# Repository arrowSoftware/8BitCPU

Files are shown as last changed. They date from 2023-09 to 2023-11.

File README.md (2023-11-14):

# 8BitCPU
8-Bit CPU

# Table of Contents
- [References](#references)
- [TODO](#todo)
- [Instruction set](#instruction-set)
  - [Instructions](#instructions)
  - [Microcodes](#microcodes)
  - [Instruction microcode decriptions](#instruction-microcode-decriptions)
  - [Logisim Instructions Testing](#logisim-instructions-testing)
    - [NOP & HLT](#nop-hlt)
    - [LDA NUM](#lda-num)
    - [LDA [ADDR]](#lda-addr)
    - [STA [ADDR]](#sta-addr)
    - [LDB [NUM]](#ldb-num)
    - [LDB [ADDR]](#ldb-addr)
    - [STB [ADDR]](#stb-addr)
    - [ADD NUM](#add-num)
    - [ADD [ADDR]](#add-addr)
    - [SUB NUM](#sub-num)
    - [SUB [ADDR]](#sub-addr)
    - [AND NUM](#add-num)
    - [AND [ADDR]](#and-addr)
    - [OR NUM](#or-num)
    - [OR [ADDR]](#or-addr)
    - [XOR NUM](#xor-num)
    - [XOR [ADDR]](#xor-addr)
    - [NOTA](#nota)
    - [NOT [ADDR]](#not-addr)
    - [OUTA](#outa)
    - [OUTB](#outb)
    - [OUT NUM](#out-num)
    - [OUT [ADDR]](#out-addr)
    - [JMP [ADDR]](#jmp-addr)
    - [JPZ [ADDR]](#jpz-addr)
    - [JPC [ADDR]](#jpc-addr)
    - [RST](#rst)
    - [Fibinacci test](#fibinacci-test)
    - [Multiplication test](#multiplication-test)
- [CPU Design](#cpu-design)
  - [Register](#register)
    - [D-Flip-Flop](#d-flip-flop)
    - [Available registers in this project](#available-registers-in-this-project)
  - [Half Adder](#half-adder)
  - [Full Adder](#full-adder)
  - [8-Bit Adder](#8-bit-adder)
  - [D-Latch](#d-latch)
  - [4-Bit Binary Decoder](#4-bit-binary-decoder)
  - [Multiplexer](#multiplexer)
    - [1-Bit Multiplexer](#1-bit-multiplexer)
    - [8-Bit Multiplexer](#8-bit-multiplexer)
    - [8-Bit 2x1 Multiplexer](#8-bit-2x1-multiplexer)
    - [8-Bit 4x1 Multiplexer](#8-bit-4x1-multiplexer)
  - [8-Bit Clear](#8-bit-clear)
  - [8-Bit Inverter](#8-bit-inverter)
  - [8-Bit OR](#8-bit-or)
  - [8-Bit AND](#8-bit-and)
  - [8-Bit XOR](#8-bit-xor)
  - [8-Bit ALU](#8-bit-alu)
  - [4-Bit Decoder - 7 Segment](#4-bit-decoder---7-segment)
  - [8-Bit Decoder - 7 Segment](#8-bit-decoder---7-segment)
  - [8-Bit Reverser](#8-bit-reverser)
  - [SRAM](#sram)
    - [16-Byte SRAM](#16-byte-sram)
    - [256-Byte SRAM](#256-byte-sram)
  - [Program Loader](#program-loader)
  - [8-Bit Processor](#8-bit-processor)
- [Assembler](#assembler)
  - [Building](#building)
  - [Number Formats](#number-formats)
  - [Label Formats](#label-formats)
  - [Instruction Formats](#instruction-formats)
  - [Output files](#output-files)
  - [Example Output](#example-output)
  - [Warnings & Errors](#warnings--errors)
  - [Reference assembler outputs](#reference-assembler-outputs)
- [Objdump](#objdump)
- [Emulator](#emulator)

## References
* https://schweigi.github.io/assembler-simulator/
* https://schweigi.github.io/assembler-simulator/instruction-set.html
* https://users.informatik.haw-hamburg.de/~krabat/FH-Labor/gnupro/5_GNUPro_Utilities/c_Using_LD/ldLinker_scripts.html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
* https://github.com/leonicolas/computer-8bits
* https://www.daniellowengrub.com/blog/2021/02/08/binary-counter
* https://github.com/hlorenzi/customasm
* https://cs.lmu.edu/~ray/notes/nasmtutorial/
### Backplane references
* https://github.com/daveho/easycpu
* https://hackaday.io/project/190621-zara80/log/218492-5-slot-stebus-backplane-rev-1
* https://tclarke.github.io/zara80/stebus-backplane.svg
* https://blondihacks.com/wp-content/uploads/2011/12/Backplane_Sch.jpg
* https://smallcomputercentral.files.wordpress.com/2018/09/modular-backplane-specification-v0-4-2018-09-19.pdf

## TODO

## Instruction set
The instruction set implemented in this project is CISC (Complex Instruction Set Computers) based.

### Instructions
|Instruction | OpCode | Description |
|:---|:---|:---|
|NOP |0x00 |No operation. Fetches the next operation.|
|HLT |0x01 |Stops the clock.|
|LDA NUM |0x02 |Loads register A with the given value.|
|LDA [ADDR]  |0x03 |Loads register A with the value stored in the given memory address.|
|STA [ADDR]  |0x04 |Stores the register A value in the given memory address.|
|LDB NUM |0x05 |Loads register B with the given value.|
|LDB [ADDR]  |0x06 |Loads register B with the value stored in the given memory address.|
|STB [ADDR]  |0x07 |Stores the register B value in the given memory address.|
|ADD NUM |0x08 |Adds the given value with the value stored in register A and stores the sum result in register A. The given number will be stored in register B.|
|ADD [ADDR]  |0x09 |Adds the value stored in the given memory address with the value stored in register A. Stores the sum result in register A.|
|SUB NUM |0x0A |Subtracts the given value with the value stored in register A and stores the subtraction result in register A. The given number will be stored in register B.|
|SUB [ADDR]  |0x0B |Subtracts the value stored in the given memory address with the value stored in register A. Stores the subtraction result in register A.|
|AND NUM |0x0C |TODO|
|ADD [ADDR]  |0x0D |TODO|
|OR NUM |0x0E |TODO|
|OR [ADDR] |0x0F |TODO|
|XOR NUM |0x10 |TODO|
|XOR [ADDR]  |0x11 |TODO|
|NOTA |0x12 |TODO|
|NOT [ADDR]  |0x13 |TODO|
|OUTA |0x14 |Sets the Output register with the register A value.|
|OUTB |0x15 |Sets the Output register with the register B value.|
|OUT NUM |0x16 |Sets the Output register with the given value.|
|OUT [ADDR]  |0x17 |Sets the Output register with the value stored in the given memory address.|
|JMP [ADDR]  |0x18 |Jumps to the given address.|
|JPZ [ADDR]  |0x19 |Jumps to the given address if the zero flag is 1.|
|JPC [ADDR]  |0x1A |Jumps to the given address if the carry flag is 1.|
|UNUSED |0x1B |Spare expansion.|
|UNUSED |0x1C |Spare expansion.|
|UNUSED |0x1D |Spare expansion.|
|RST |0x1E |Reset the cpu (TODO).|

### Microcodes
* FLG = FLAG REGISTER
  * FI = Enable flag register load.
    * Loads the flags register with the value currently on the data bus.
    * Available flags:
    * | Flag | Description   |
      |------|---------------|
      | CF   | Carry Flag    |
      | ZF   | Zero Flag     |
      | NF   | Negative Flag |
      | VF   | Overflow Flag |
* CL = CLOCK
  * HL = Halt clock.
    * Stops the clock.
* AR = A REGISTER
  * AI = Enable A register load.
    * Loads the A register with the value currently on the data bus.
  * AO = Enable A regsiter output.
    * Outputs the current register value to the data bus.
* ALU = ALGORITHMIC AND LOGIC UNIT
  * EO = Enable ALU output.
    * Outputs the current ALU operation result to the data bus.
  * CI = Carry in flag.
    * Carry in flag from Flag register
  * SEL = ALU operation select code
    * 3 bit number for selecting the ALU operation.
    * | code | operation      |
      |------|----------------|
      |000   | A OR B         |
      |001   | NOT A          |
      |010   | A + NOT B + Ci |
      |011   | A + B + Ci     |
      |100   | A XOR B        |
      |101   | A AND B        |
      |110   | A - 1 + Ci     |
* BR = B REGISTER
  * BI = Enable B register load.
    * Loads the A register with the value currently on the data bus.
  * BO = Enable B regsiter output.
    * Outputs the current register value to the data bus.
* MR = MEMORY REGISTER
  * MI = Enable memory register load.
    * Loads the memory register with the value currently on the data bus.
* RAM = RANDOM ACCESS MEMORY
  * RW = Enable RAM write.
    * Writes the value currently on the data bus into the selected memory banks.
  * RR = Enable RAM read.
    * Outputs the value stored in the selected memory bank to the data bus.
* IR = INSTRUCTION REGISTER
  * II = Enable instruction register load.
    * Loads the instruction register with the value currently on the data bus.
  * IR = Reset instruction register.
    * Resets the instruction decoder counter back to 0. (Fetch next instruction set)
* PC = PROGRAM COUNTER REGISTER
  * CE = Enable counter register.
    * Enables the program counter to process the count.
  * CO = Enable counter register output.
    * Ouputs the current register value to the data bus.
  * JP = Enable counter register load.
    * Loads the program counter register with the value currently on the data bus.
* OR = OUTPUT REGISTER
  * OI = Enable output register load.
    * Loads the output register with the value currently on the data bus.

### Instruction microcode decriptions

* Control Flags is a bit mapping of each microword.
* OpCode in column 2 is the assembly opcode value.
* OpCode in second to last column is the microcode opcode value.

| Instruction | OpCode |CF |ZF |VF |NF |Step  |FI |HL |AI |AO |SEL  |EO |CI |BI |BO |MI |RW |RR |II |IR |CE |CO |JP |OI |OpCode  |Control Flags  |
|:---|:---:|:-:|:-:|:-:|:-:|:----:|:-:|:-:|:-:|:-:|:---:|:-:|:-:|:-:|:-:|:-:|:-:|:-:|:-:|:-:|:-:|:-:|:-:|:-:|:---:|:---:|
|FETCH INSTR  |XXXXX | X | X | X | X |0 | 0 | 0 | 0 | 0 | XXX | 0 | 0 | 0 | 0 | 1 | 0 | 0 | 0 | 0 | 0 | 1 | 0 | 0 | XX | 00104 |
| |XXXXX | X | X | X | X |1 | 0 | 0 | 0 | 0 | XXX | 0 | 0 | 0 | 0 | 0 | 0 | 1 | 1 | 0 | 1 | 0 | 0 | 0 | XX | 00068 |
|FIN INSTR |XXXXX | X | X | X | X |X | X | X | X | 0 | XXX | 0 | 0 | 0 | 0 | 0 | 0 | 0 | 0 | 1 | 0 | 0 | 0 | 0 | XX | 00010 |
| | | | | | | | | | | | | | | | | | | | | | | | | | | |
|NOP |00000 | X | X | X | X |2 | 0 | 0 | 0 | 0 | XXX | 0 | 0 | 0 | 0 | 0 | 0 | 0 | 0 | 1 | 0 | 0 | 0 | 0 | 00 | 00010 |
|HLT |00001 | X | X | X | X |2 | 0 | 1 | 0 | 0 | XXX | 0 | 0 | 0 | 0 | 0 | 0 | 0 | 0 | 0 | 0 | 0 | 0 | 0 | 01 | 40000 |
|LDA NUM |00010 | X | X | X | X |2 | 0 | 0 | 0 | 0 | XXX | 0 | 0 | 0 | 0 | 1 | 0 | 0 | 0 | 0 | 1 | 1 | 0 | 0 | 02 | 0010C |
| |00010 | X | X | X | X |3 | 0 | 0 | 1 | 0 | XXX | 0 | 0 | 0 | 0 | 0 | 0 | 1 | 0 | 0 | 0 | 0 | 0 | 0 | 02 | 20040 |
|LDA [ADDR] |00011 | X | X | X | X |2 | 0 | 0 | 0 | 0 | XXX | 0 | 0 | 0 | 0 | 1 | 0 | 0 | 0 | 0 | 1 | 1 | 0 | 0 | 03 | 0010C |
| |00011 | X | X | X | X |3 | 0 | 0 | 0 | 0 | XXX | 0 | 0 | 0 | 0 | 1 | 0 | 1 | 0 | 0 | 0 | 0 | 0 | 0 | 03 | 00140 |
| |00011 | X | X | X | X |4 | 0 | 0 | 1 | 0 | XXX | 0 | 0 | 0 | 0 | 0 | 0 | 1 | 0 | 0 | 0 | 0 | 0 | 0 | 03 | 20040 |
|STA [ADDR] |00100 | X | X | X | X |2 | 0 | 0 | 0 | 0 | XXX | 0 | 0 | 0 | 0 | 1 | 0 | 0 | 0 | 0 | 1 | 1 | 0 | 0 | 04 | 0010C |
| | | X | X | X | X |3 | 0 | 0 | 0 | 0 | XXX | 0 | 0 | 0 | 0 | 1 | 0 | 1 | 0 | 0 | 0 | 0 | 0 | 0 | 04 | 00140 |
| | | X | X | X | X |4 | 0 | 0 | 0 | 1 | XXX | 0 | 0 | 0 | 0 | 0 | 1 | 0 | 0 | 0 | 0 | 0 | 0 | 0 | 04 | 10080 |
|LDB NUM |00101 | X | X | X | X |2 | 0 | 0 | 0 | 0 | XXX | 0 | 0 | 0 | 0 | 1 | 0 | 0 | 0 | 0 | 1 | 1 | 0 | 0 | 05 | 0010C |
| | | X | X | X | X |3 | 0 | 0 | 0 | 0 | XXX | 0 | 0 | 1 | 0 | 0 | 0 | 1 | 0 | 0 | 0 | 0 | 0 | 0 | 05 | 00440 |
|LDB [ADDR] |00110 | X | X | X | X |2 | 0 | 0 | 0 | 0 | XXX | 0 | 0 | 0 | 0 | 1 | 0 | 0 | 0 | 0 | 1 | 1 | 0 | 0 | 06 | 0010C |
| | | X | X | X | X |3 | 0 | 0 | 0 | 0 | XXX | 0 | 0 | 0 | 0 | 1 | 0 | 1 | 0 | 0 | 0 | 0 | 0 | 0 | 06 | 00140 |
| | | X | X | X | X |4 | 0 | 0 | 0 | 0 | XXX | 0 | 0 | 1 | 0 | 0 | 0 | 1 | 0 | 0 | 0 | 0 | 0 | 0 | 06 | 00440 |
|STB [ADDR] |00111 | X | X | X | X |2 | 0 | 0 | 0 | 0 | XXX | 0 | 0 | 0 | 0 | 1 | 0 | 0 | 0 | 0 | 1 | 1 | 0 | 0 | 07 | 0010C |
| | | X | X | X | X |3 | 0 | 0 | 0 | 0 | XXX | 0 | 0 | 0 | 0 | 1 | 0 | 1 | 0 | 0 | 0 | 0 | 0 | 0 | 07 | 00140 |
| | | X | X | X | X |4 | 0 | 0 | 0 | 0 | XXX | 0 | 0 | 0 | 1 | 0 | 1 | 0 | 0 | 0 | 0 | 0 | 0 | 0 | 07 | 00280 |
|ADD NUM |01000 | 0 | X | X | X |2 | 0 | 0 | 0 | 0 | 001 | 0 | 0 | 0 | 0 | 1 | 0 | 0 | 0 | 0 | 1 | 1 | 0 | 0 | 08 | 0010C |
| | | 0 | X | X | X |3 | 0 | 0 | 0 | 0 | 001 | 0 | 0 | 1 | 0 | 0 | 0 | 1 | 0 | 0 | 0 | 0 | 0 | 0 | 08 | 00440 |
| | | 0 | X | X | X |4 | 1 | 0 | 1 | 0 | 001 | 1 | 0 | 0 | 0 | 0 | 0 | 0 | 0 | 0 | 0 | 0 | 0 | 0 | 08 | A1000 |
|ADD [ADDR] |01001 | 0 | X | X | X |2 | 0 | 0 | 0 | 0 | 001 | 0 | 0 | 0 | 0 | 1 | 0 | 0 | 0 | 0 | 1 | 1 | 0 | 0 | 09 | 0010C |
| | | 0 | X | X | X |3 | 0 | 0 | 0 | 0 | 001 | 0 | 0 | 0 | 0 | 1 | 0 | 1 | 0 | 0 | 0 | 0 | 0 | 0 | 09 | 00140 |
| | | 0 | X | X | X |4 | 0 | 0 | 0 | 0 | 001 | 0 | 0 | 1 | 0 | 0 | 0 | 1 | 0 | 0 | 0 | 0 | 0 | 0 | 09 | 00440 |
| | | 0 | X | X | X |5 | 1 | 0 | 1 | 0 | 001 | 1 | 0 | 0 | 0 | 0 | 0 | 0 | 0 | 0 | 0 | 0 | 0 | 0 | 09 | A1000 |
|SUB NUM |01010 | 1 | X | X | X |2 | 0 | 0 | 0 | 0 | 001 | 0 | 0 | 0 | 0 | 1 | 0 | 0 | 0 | 0 | 1 | 1 | 0 | 0 | 0A | 0010C |
| | | 1 | X | X | X |3 | 0 | 0 | 0 | 0 | 001 | 0 | 1 | 1 | 0 | 0 | 0 | 1 | 0 | 0 | 0 | 0 | 0 | 0 | 0A | 00C40 |
| | | 1 | X | X | X |4 | 1 | 0 | 1 | 0 | 001 | 1 | 1 | 0 | 0 | 0 | 0 | 0 | 0 | 0 | 0 | 0 | 0 | 0 | 0A | A1800 |
|SUB [ADDR] |01011 | 1 | X | X | X |2 | 0 | 0 | 0 | 0 | 001 | 0 | 0 | 0 | 0 | 1 | 0 | 0 | 0 | 0 | 1 | 1 | 0 | 0 | 0B | 0010C |
| | | 1 | X | X | X |3 | 0 | 0 | 0 | 0 | 001 | 0 | 0 | 0 | 0 | 1 | 0 | 1 | 0 | 0 | 0 | 0 | 0 | 0 | 0B | 00140 |
| | | 1 | X | X | X |4 | 0 | 0 | 0 | 0 | 001 | 0 | 1 | 1 | 0 | 0 | 0 | 1 | 0 | 0 | 0 | 0 | 0 | 0 | 0B | 00C40 |
| | | 1 | X | X | X |5 | 1 | 0 | 1 | 0 | 001 | 1 | 1 | 0 | 0 | 0 | 0 | 0 | 0 | 0 | 0 | 0 | 0 | 0 | 0B | A1800 |
|AND NUM |01100 | 1 | 1 | X | X |TODO  | | | | | | | | | | | | | | | | | | | 0C | 00000 |
|AND [ADDR] |01101 | 1 | 1 | X | X |TODO  | | | | | | | | | | | | | | | | | | | 0D | 00000 |
|OR NUM |01110 | 1 | 1 | X | X |TODO  | | | | | | | | | | | | | | | | | | | 0E | 00000 |
|OR [ADDR] |01111 | 1 | 1 | X | X |TODO  | | | | | | | | | | | | | | | | | | | 0F | 00000 |
|XOR NUM |10000 | 1 | 1 | X | X |TODO  | | | | | | | | | | | | | | | | | | | 10 | 00000 |
|XOR [ADDR] |10001 | 1 | 1 | X | X |TODO  | | | | | | | | | | | | | | | | | | | 11 | 00000 |
|NOTA |10010 | X | 1 | X | X |TODO  | | | | | | | | | | | | | | | | | | | 12 | 00000 |
|NOT [ADDR] |10011 | X | 1 | X | X |TODO  | | | | | | | | | | | | | | | | | | | 13 | 00000 |
|OUTA |10100 | X | X | X | X |2 | 0 | 0 | 0 | 1 | 000 | 0 | 0 | 0 | 0 | 0 | 0 | 0 | 0 | 0 | 0 | 0 | 0 | 1 | 14 | 10001 |
|OUTB |10101 | X | X | X | X |2 | 0 | 0 | 0 | 0 | 000 | 0 | 0 | 0 | 1 | 0 | 0 | 0 | 0 | 0 | 0 | 0 | 0 | 1 | 15 | 00201 |
|OUT NUM |10110 | X | X | X | X |2 | 0 | 0 | 0 | 0 | 000 | 0 | 0 | 0 | 0 | 1 | 0 | 0 | 0 | 0 | 1 | 1 | 0 | 0 | 16 | 0010C |
| | | X | X | X | X |3 | 0 | 0 | 0 | 0 | 000 | 0 | 0 | 0 | 0 | 0 | 0 | 1 | 0 | 0 | 0 | 0 | 0 | 1 | 16 | 00041 |
|OUT [ADDR] |10111 | X | X | X | X |2 | 0 | 0 | 0 | 0 | 000 | 0 | 0 | 0 | 0 | 1 | 0 | 0 | 0 | 0 | 1 | 1 | 0 | 0 | 17 | 0010C |
| | | X | X | X | X |3 | 0 | 0 | 0 | 0 | 000 | 0 | 0 | 0 | 0 | 1 | 0 | 1 | 0 | 0 | 0 | 0 | 0 | 0 | 17 | 00140 |
| | | X | X | X | X |4 | 0 | 0 | 0 | 0 | 000 | 0 | 0 | 0 | 0 | 0 | 0 | 1 | 0 | 0 | 0 | 0 | 0 | 1 | 17 | 00041 |
|JMP [ADDR] |11000 | X | X | X | X |2 | 0 | 0 | 0 | 0 | 000 | 0 | 0 | 0 | 0 | 1 | 0 | 0 | 0 | 0 | 1 | 1 | 0 | 0 | 18 | 0010C |
| | | X | X | X | X |3 | 0 | 0 | 0 | 0 | 000 | 0 | 0 | 0 | 0 | 0 | 0 | 1 | 0 | 0 | 0 | 0 | 1 | 0 | 18 | 00042 |
|JPZ [ADDR] |11001 | X | 0 | X | X |2 | 0 | 0 | 0 | 0 | 000 | 0 | 0 | 0 | 0 | 0 | 0 | 0 | 0 | 0 | 1 | 0 | 0 | 0 | 19 | 00008 |
|JPZ [ADDR] |11001 | X | 1 | X | X |2 | 0 | 0 | 0 | 0 | 000 | 0 | 0 | 0 | 0 | 1 | 0 | 0 | 0 | 0 | 1 | 1 | 0 | 0 | 19 | 0010C |
| | | X | 1 | X | X |3 | 0 | 0 | 0 | 0 | 000 | 0 | 0 | 0 | 0 | 0 | 0 | 1 | 0 | 0 | 0 | 0 | 1 | 0 | 19 | 00042 |
|JPC [ADDR] |11001 | 0 | X | X | X |2 | 0 | 0 | 0 | 0 | 000 | 0 | 0 | 0 | 0 | 0 | 0 | 0 | 0 | 0 | 1 | 0 | 0 | 0 | 1A | 00008 |
|JPC [ADDR] |11010 | 1 | X | X | X |2 | 0 | 0 | 0 | 0 | 000 | 0 | 0 | 0 | 0 | 1 | 0 | 0 | 0 | 0 | 1 | 1 | 0 | 0 | 1A | 0010C |
| |11011 | 1 | X | X | X |3 | 0 | 0 | 0 | 0 | 000 | 0 | 0 | 0 | 0 | 0 | 0 | 1 | 0 | 0 | 0 | 0 | 1 | 0 | 1A | 00042 |
|UNUSED |11100 | | | | | | | | | | | | | | | | | | | | | | | | 1B | 00000 |
|UNUSED |11101 | | | | | | | | | | | | | | | | | | | | | | | | 1C | 00000 |
|UNUSED |11110 | | | | | | | | | | | | | | | | | | | | | | | | 1D | 00000 |
|RST |11111 | | | | |TODO  | | | | | | | | | | | | | | | | | | | 1E | 00000 |

### Logisim Instructions Testing

#### NOP & HLT
```nasm
00:  NOP # No operation
01:  HLT # Halt the clock
```
```nasm
v2.0 raw
00
01
```
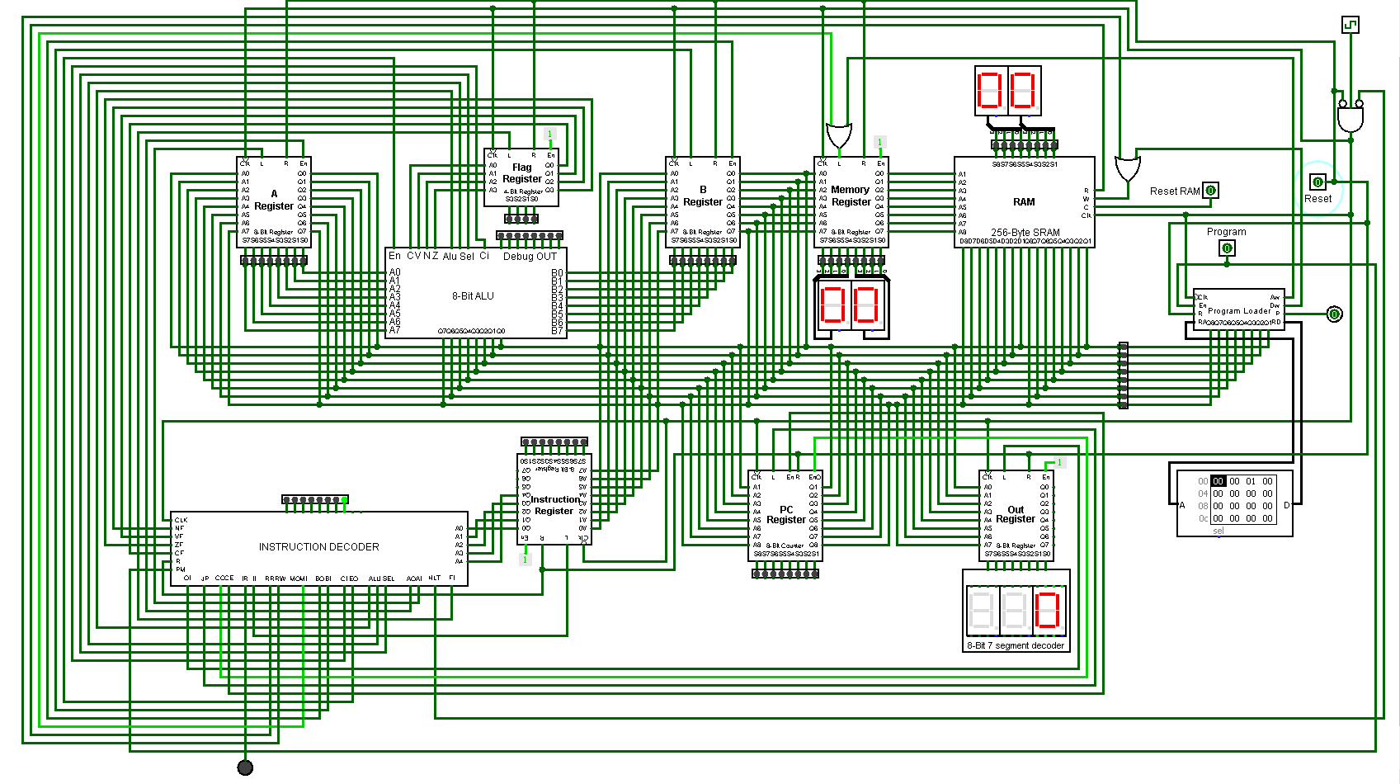
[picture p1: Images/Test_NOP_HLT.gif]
NOP and HLT test


#### LDA NUM
```nasm
00:  LDA 0x55 # Load A register with value 0x55
02:  HLT # Halt the clock
```
```nasm
v2.0 raw
02 55
01
```
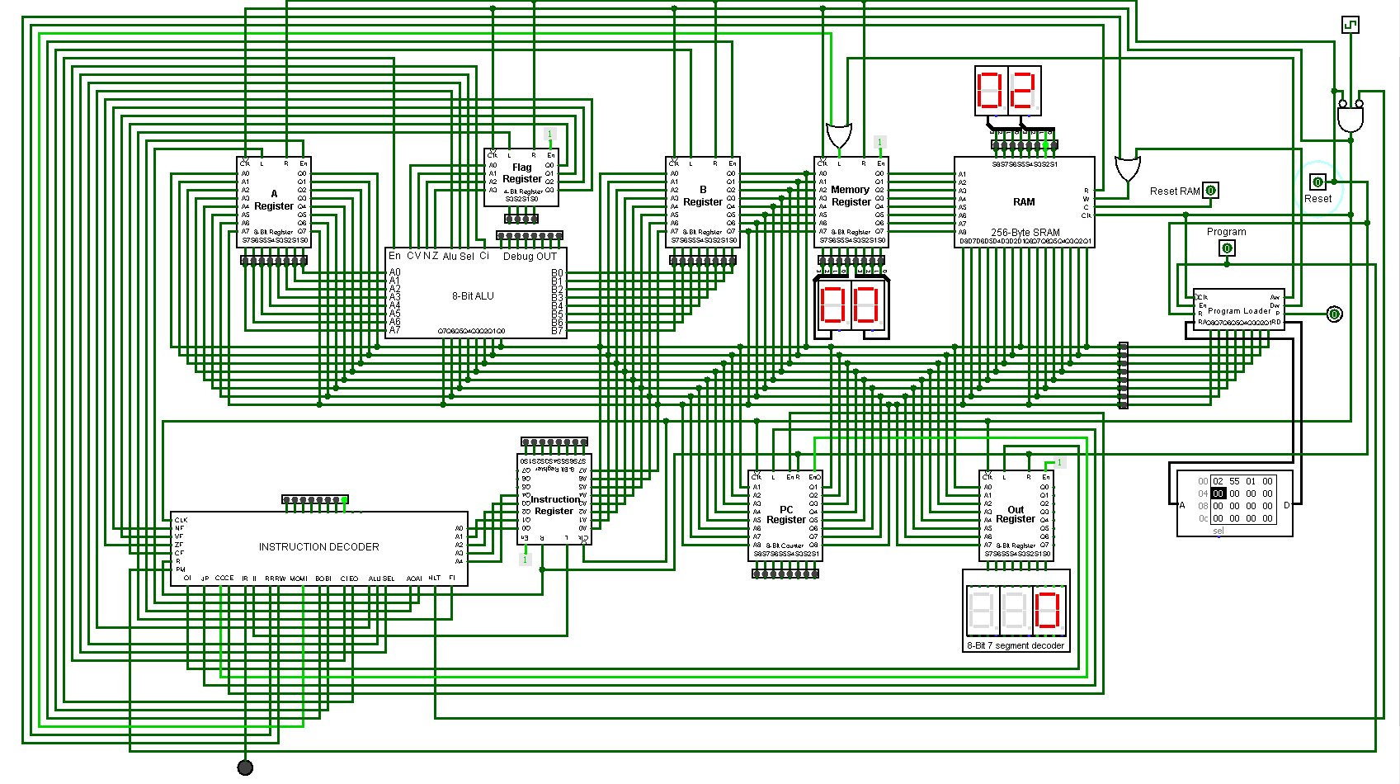
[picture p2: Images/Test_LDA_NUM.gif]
LDA NUM test


#### LDA [ADDR]
```nasm
# 0x04 variable

00:  LDA [variable] # Load A register with value at address [variable]
02:  HLT # Halt the clock
```
```nasm
v2.0 raw
03 04
01 00
aa 00
```
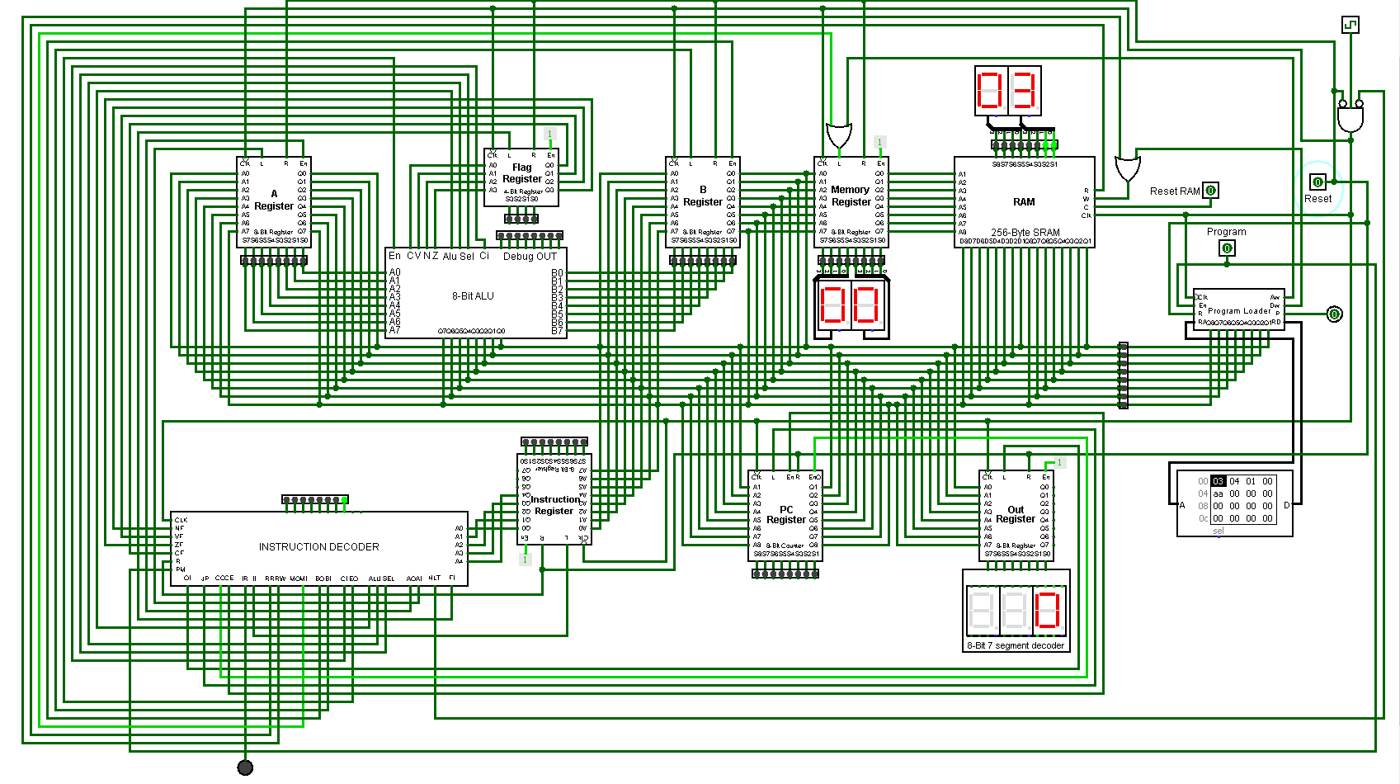
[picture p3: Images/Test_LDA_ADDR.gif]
LDA ADDR test


#### STA [ADDR]
```nasm
# 0x05 variablePtr

00: LDA 0xAA # Load A register with value 0xAA
02: STA [variablePtr] # Store value in A register at memory address [variablePtr]
04: HLT # Halt the clock
```
```nasm
v2.0 raw
02 55
04 05
01
```
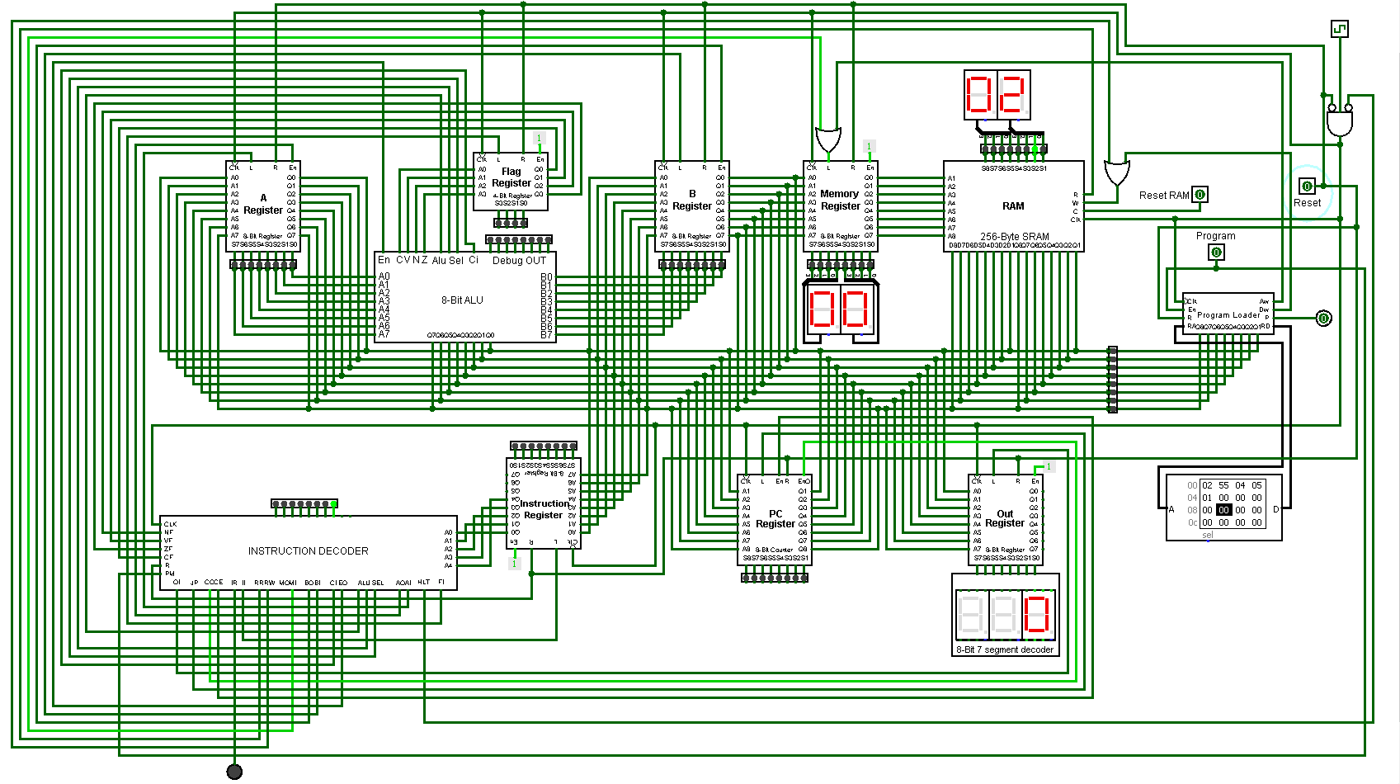
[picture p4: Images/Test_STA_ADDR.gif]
STA ADDR test


#### LDB [NUM]
```nasm
00:  LDB 0x55 # Load B register with value 0x55
02:  HLT # Halt the clock
```
```nasm
v2.0 raw
05 55
01
```
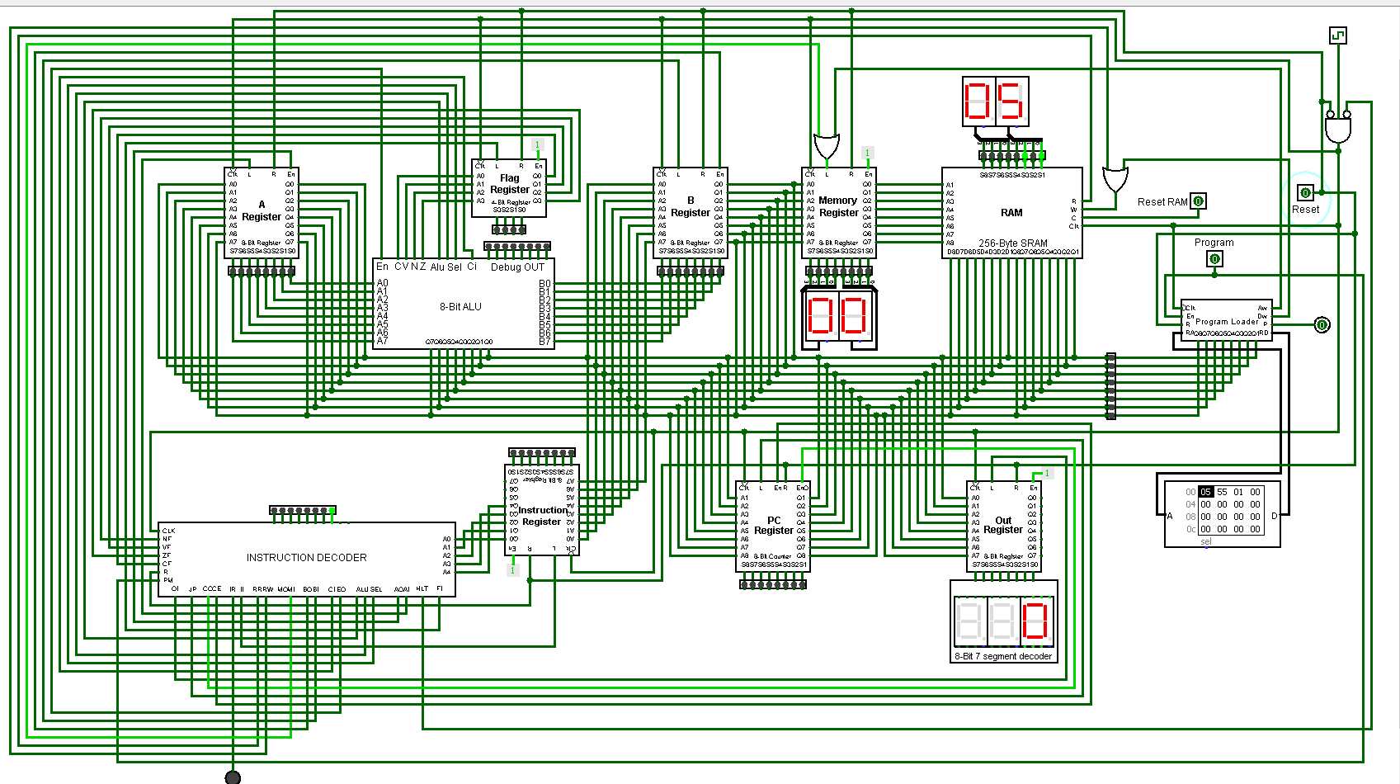
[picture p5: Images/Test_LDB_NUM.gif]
LDB NUM test


#### LDB [ADDR]
```nasm
# 0x04 variable

00:  LDB [variable] # Load B register with value at address [variable]
02:  HLT # Halt the clock
```
```nasm
v2.0 raw
06 04
01 00
aa 00
```
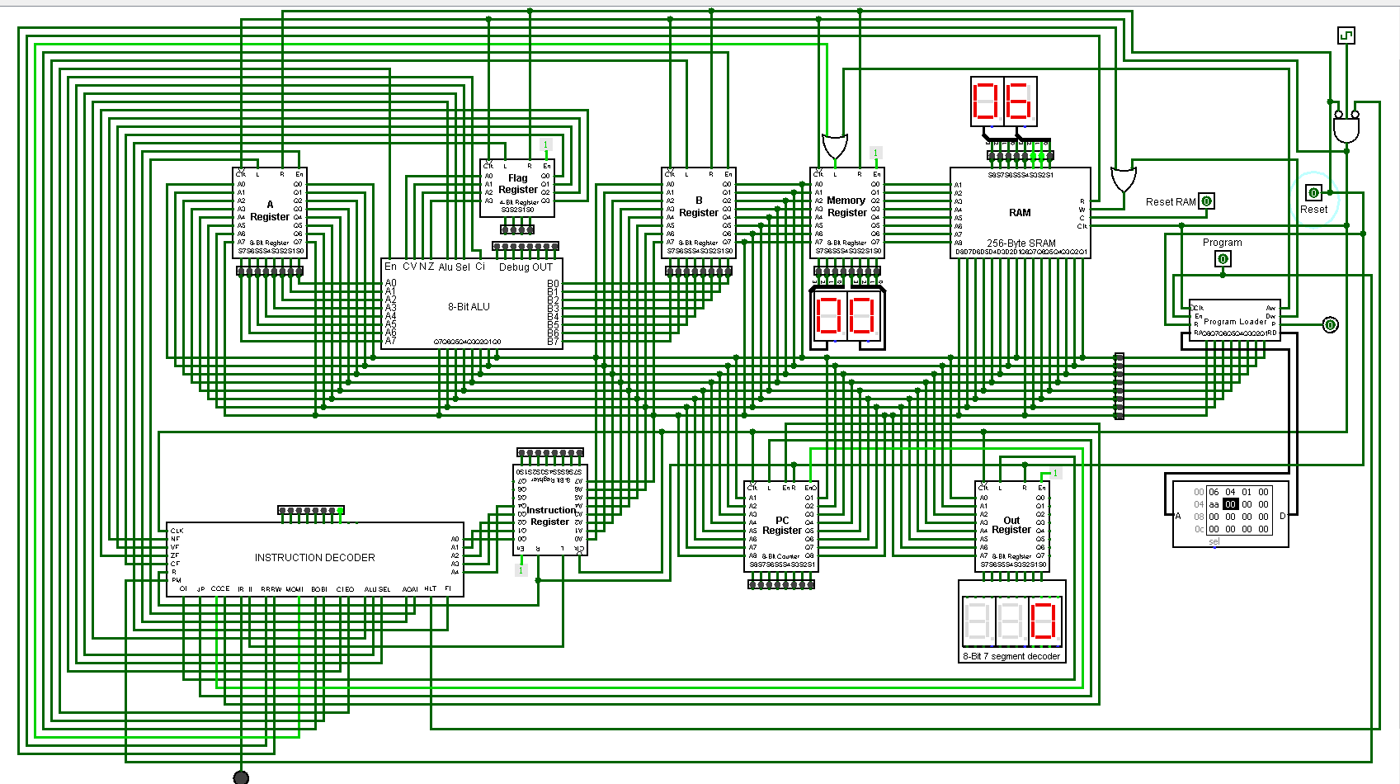
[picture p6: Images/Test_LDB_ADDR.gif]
LDB ADDR test


#### STB [ADDR]
```nasm
# 0x05 variablePtr

00: LDB 0xAA # Load B register with value 0xAA
02: STB [variablePtr] # Store value in B register at memory address [variablePtr]
04: HLT # Halt the clock
```
```nasm
v2.0 raw
05 55
07 05
01
```
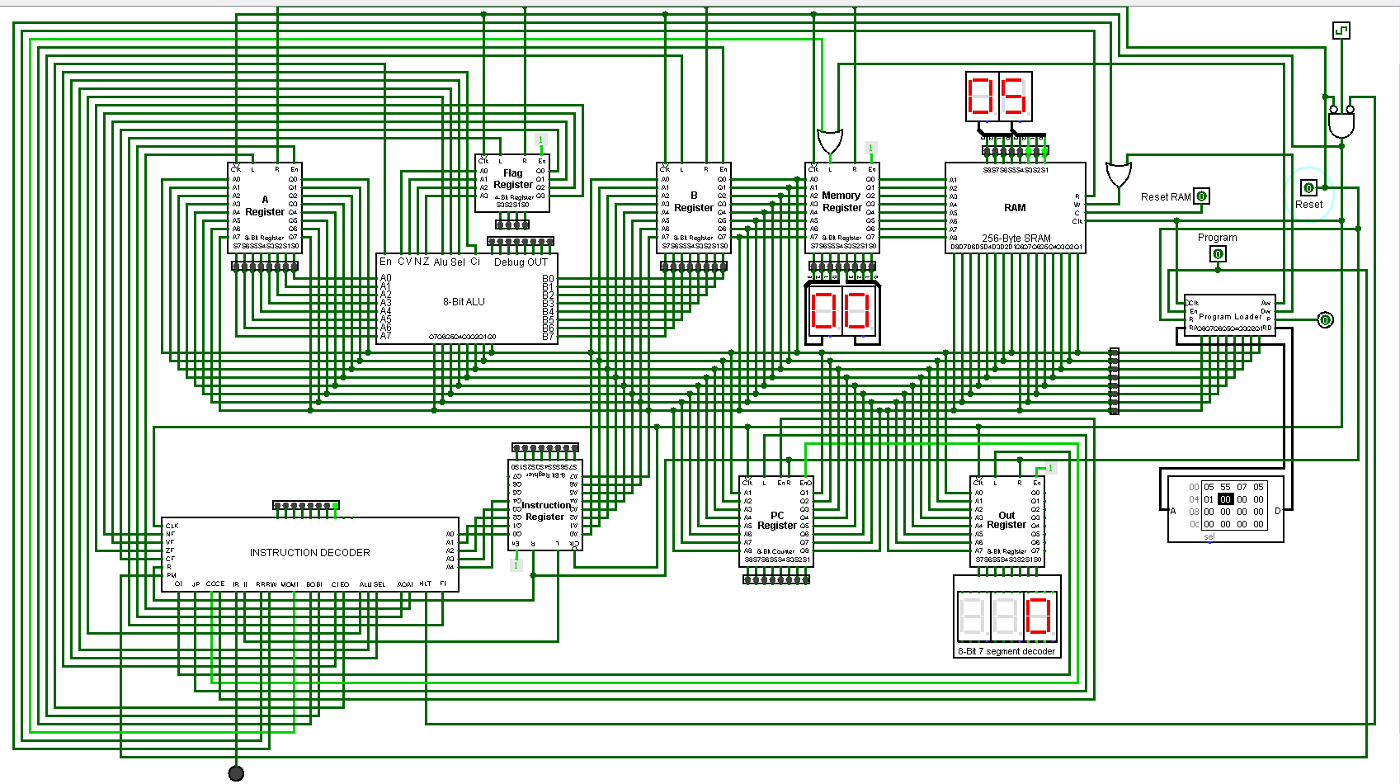
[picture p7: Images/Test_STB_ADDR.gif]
STB ADDR test


#### ADD NUM
```nasm
00: LDA 0x02 # Load A register with value 0x02
02: ADD 0x04 # Add 0x04 to the value in A register and store output in A register
04: OUTA # Load output register with the value in the A register
05: HLT # halt the clock
```
```nasm
v2.0 raw
02 02
08 04
14
01
```
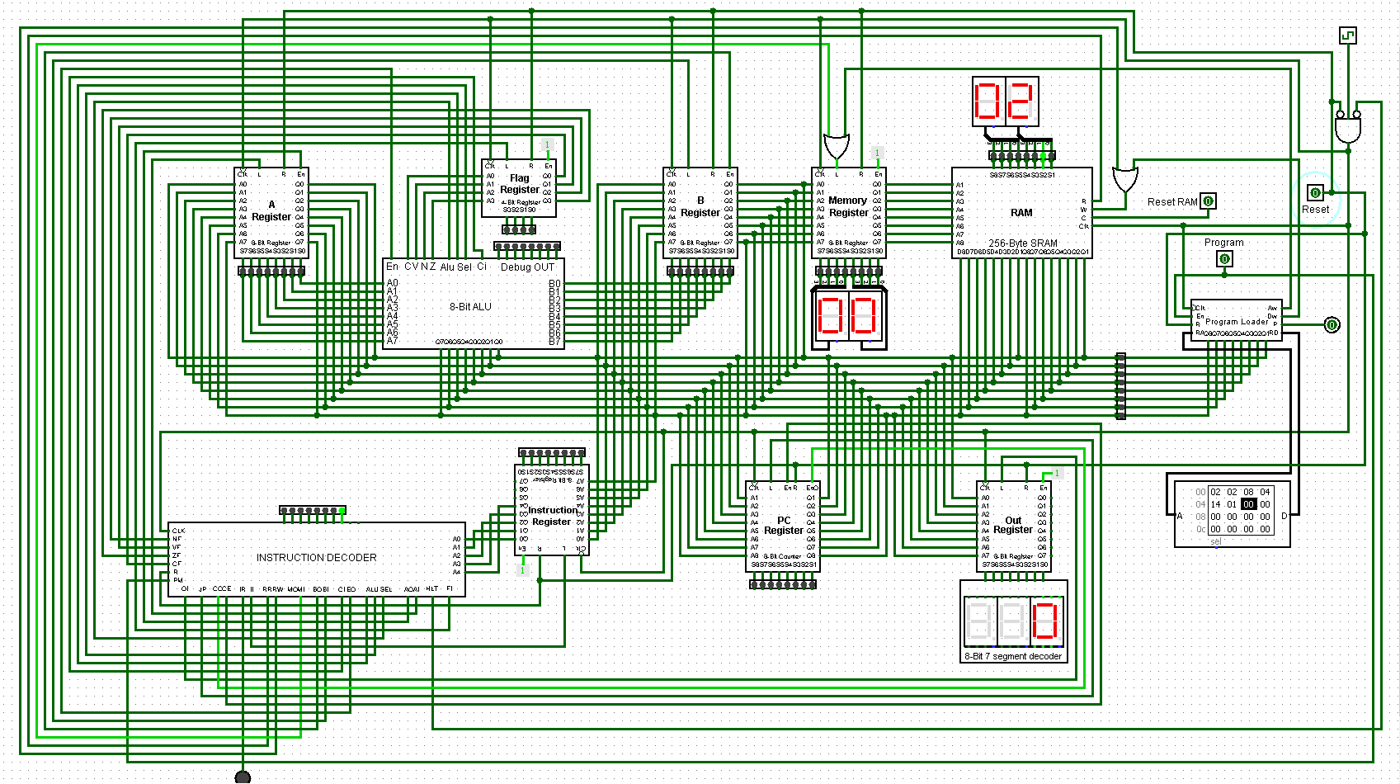
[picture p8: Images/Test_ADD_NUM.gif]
ADD NUM test


#### ADD [ADDR]
```nasm
# 0x07 variablePtr

00: LDA 0x5
02: ADD [variablePtr] # Add the value in memory address [variablePtr] to the value in the A register and store the output in the A register
04: OUTA # Load output register with the value in the A register
05: HLT # halt the clock
```
```nasm
v2.0 raw
02 05
09 07
14
01
00
05
```
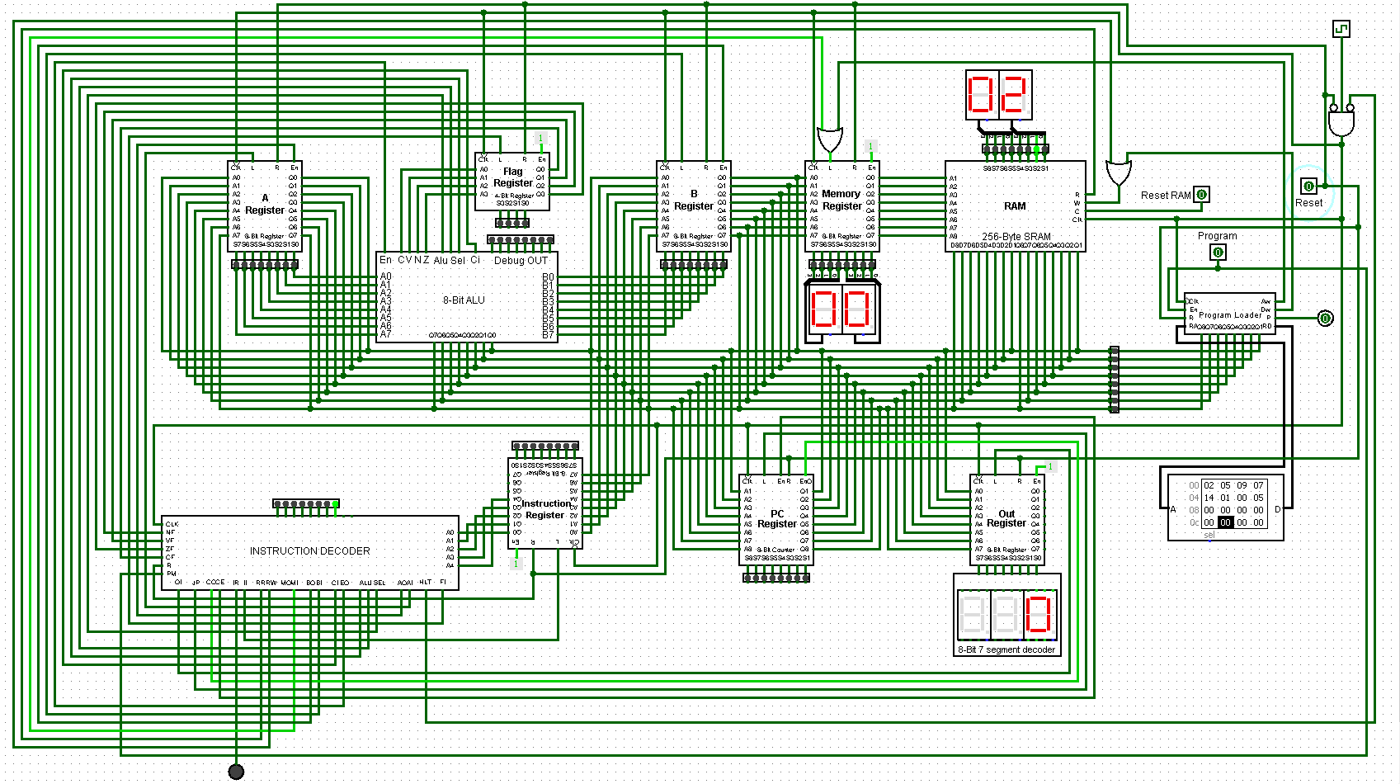
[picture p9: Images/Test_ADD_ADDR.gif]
ADD ADDR test


#### SUB NUM
```nasm
00: LDA 0x08
02: SUB 0x02
04: OUTA
05: HLT
```
``` nasm
v2.0 raw
02 08
0A 02
14
01
```
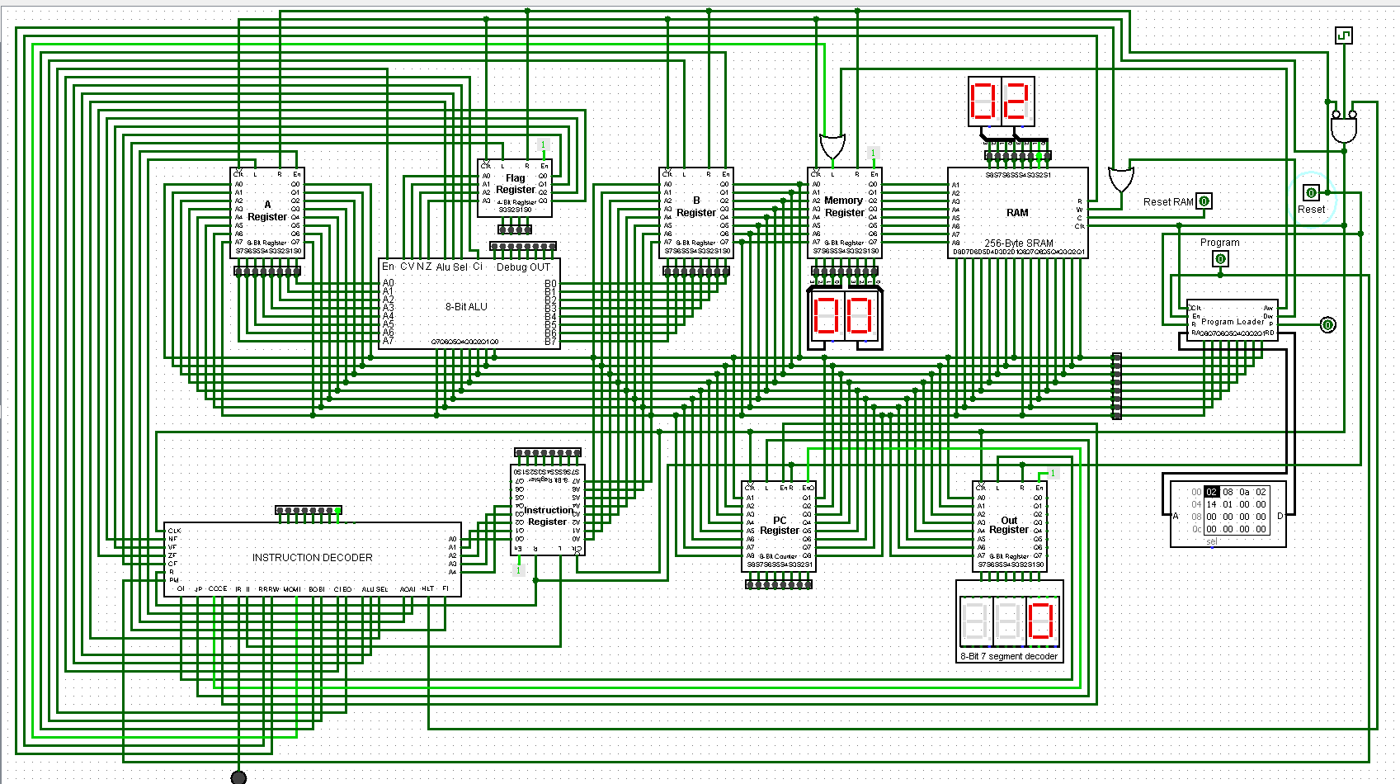
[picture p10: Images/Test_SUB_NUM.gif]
SUB NUM test


#### SUB [ADDR]
```nasm
# 0x07 variablePtr

00: LDA 0x08
02: SUB [variablePtr] # Subtract the value in memory address [variablePtr] from the value in the A register and store the output in the A register
04: OUTA
05: HLT
```
``` nasm
v2.0 raw
02 08
0B 07
14
01
00
02
```
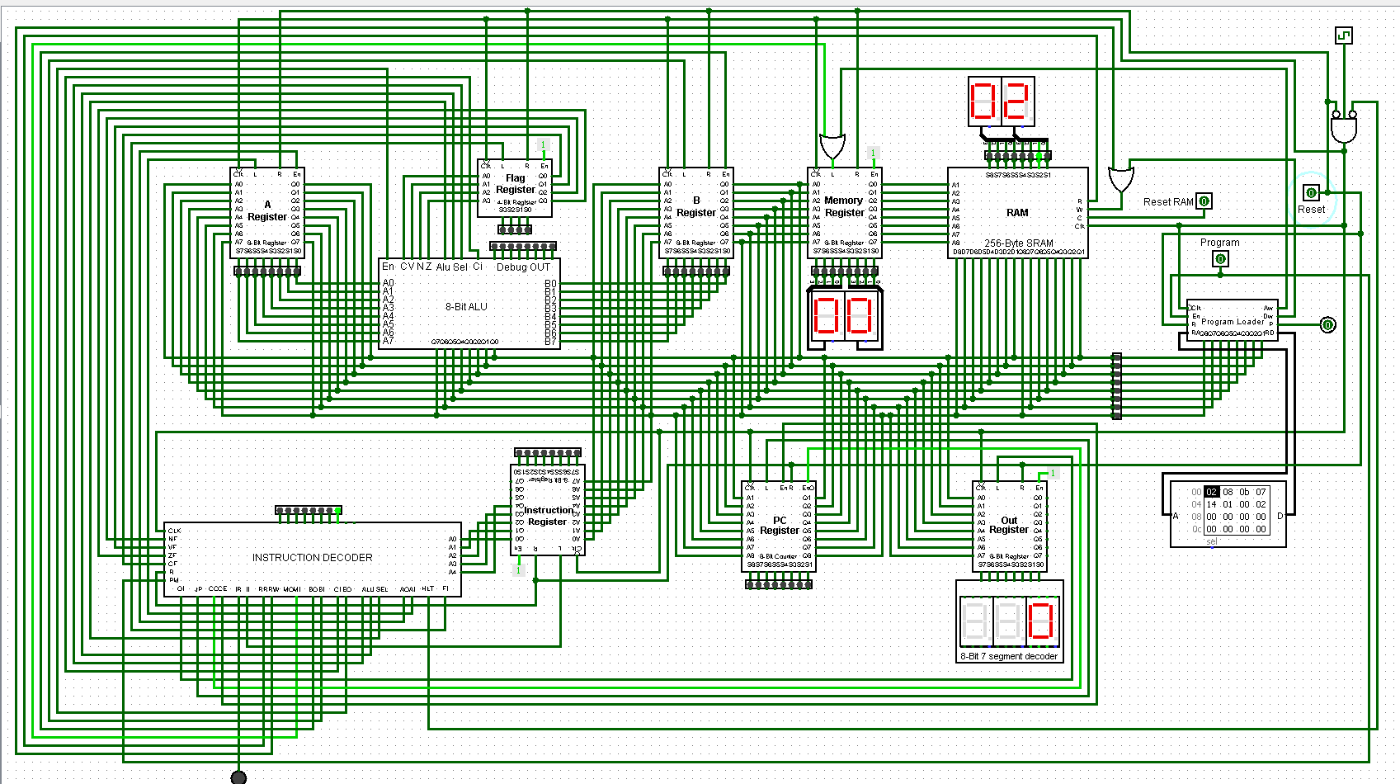
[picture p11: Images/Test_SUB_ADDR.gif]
SUB ADDR test


#### AND NUM
```nasm
TODO
```
```nasm
v2.0 raw
```
AND NUM test

#### AND [ADDR]
```nasm
TODO
```
```nasm
v2.0 raw
```
AND [ADDR] test

#### OR NUM
```nasm
TODO
```
```nasm
v2.0 raw
```
OR NUM test

#### OR [ADDR]
```nasm
TODO
```
```nasm
v2.0 raw
```
OR [ADDR] test

#### XOR NUM
```nasm
TODO
```
```nasm
v2.0 raw
```
XOR NUM test

#### XOR [ADDR]
```nasm
TODO
```
```nasm
v2.0 raw
```
XOR [ADDR] test

#### NOTA
```nasm
TODO
```
```nasm
v2.0 raw
```
NOTA test

#### NOT [ADDR]
```nasm
TODO
```
```nasm
v2.0 raw
```
NOT [ADDR] test

#### OUTA
```nasm
00: LDA 0x55 # Load A register with value 0x55
02: OUTA
03: HLT
```
```nasm
v2.0 raw
02 55
14
01
```
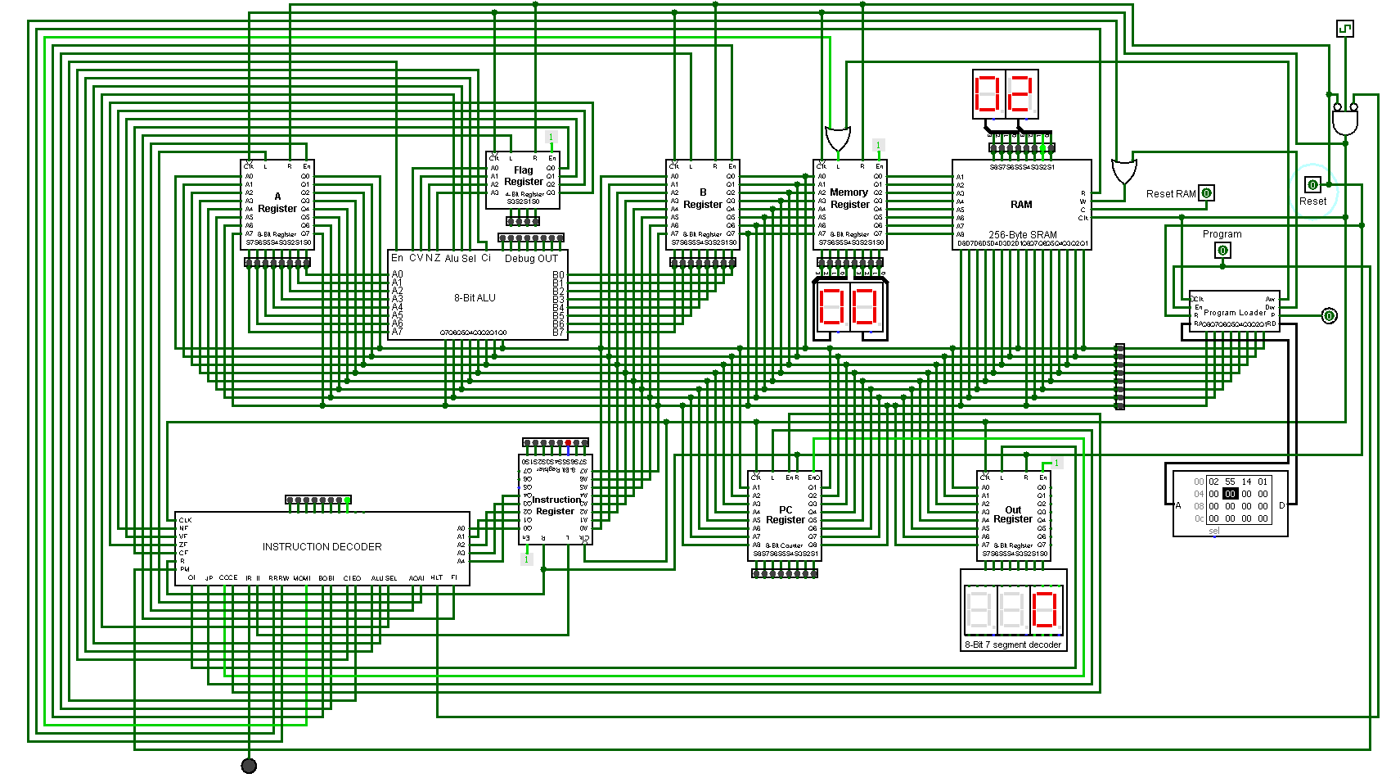
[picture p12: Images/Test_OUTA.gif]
OUTA test


#### OUTB
```nasm
00: LDB 0x55 # Load B register with value 0x55
02: OUTB
03: HLT
```
```nasm
v2.0 raw
05 55
15
01
```
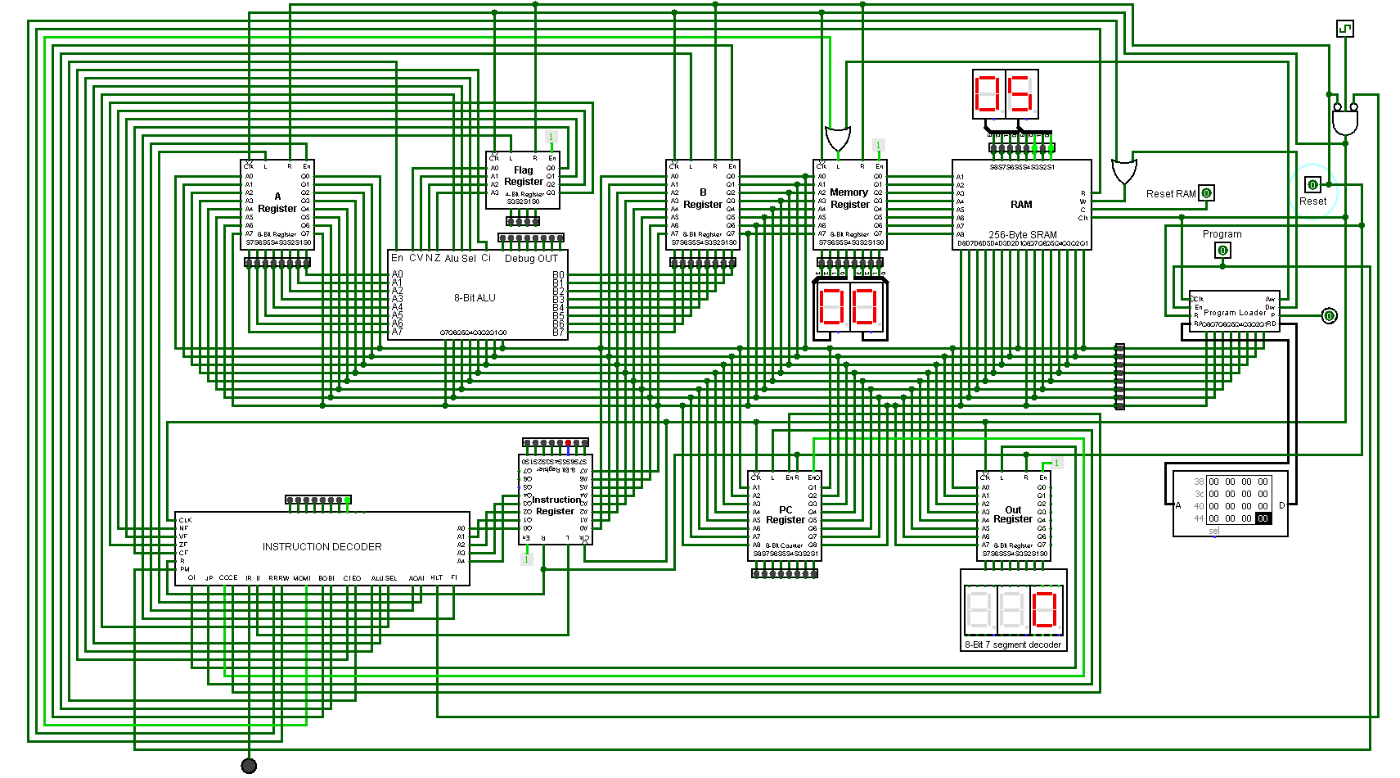
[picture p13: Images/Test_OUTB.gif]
OUTB test


#### OUT NUM
```nasm
00: OUT 0xAA
02: HLT
```
```nasm
v2.0 raw
16 aa
01
```
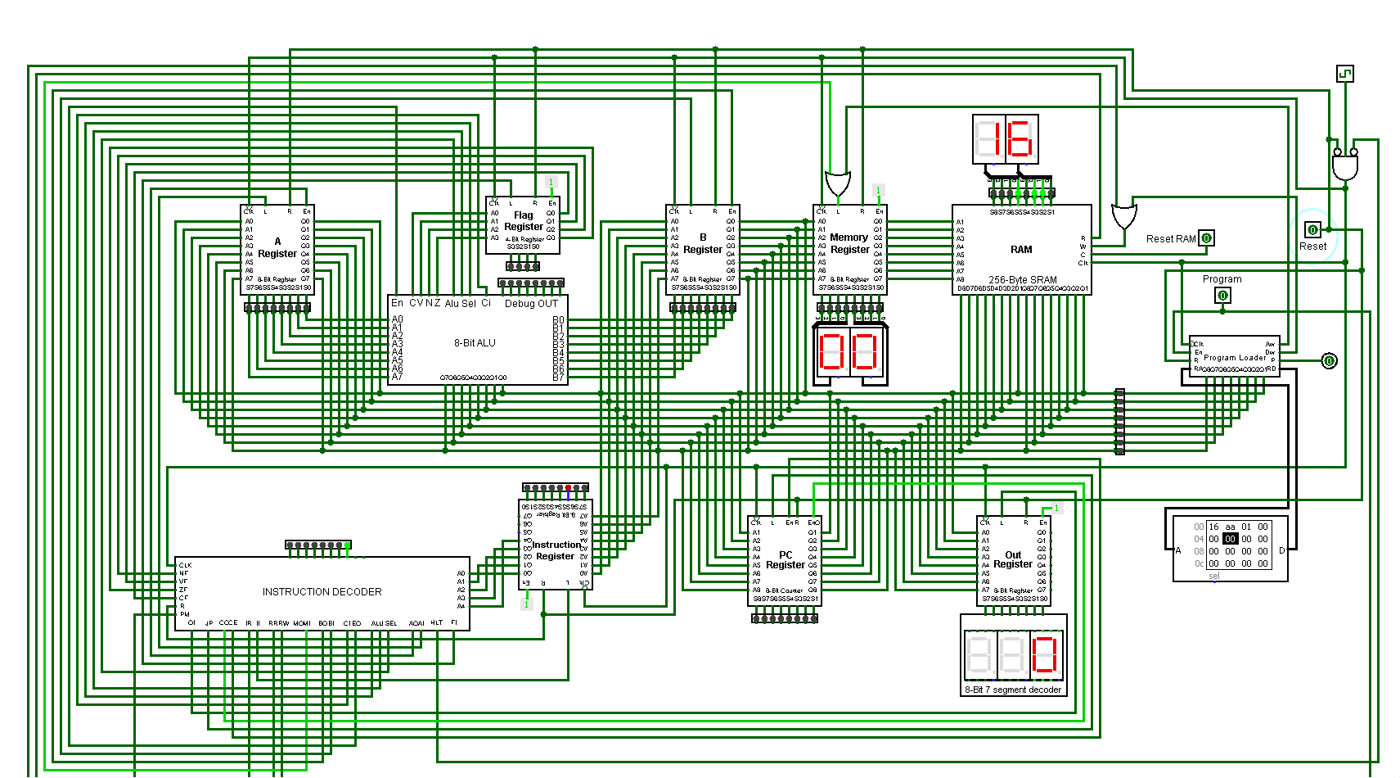
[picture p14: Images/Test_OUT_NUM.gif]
OUT NUM test


#### OUT [ADDR]
```nasm
# 0x04 variablePtr

00: OUT [variablePtr]
02: HLT

```
```nasm
v2.0 raw
17 04
01
00
55
```
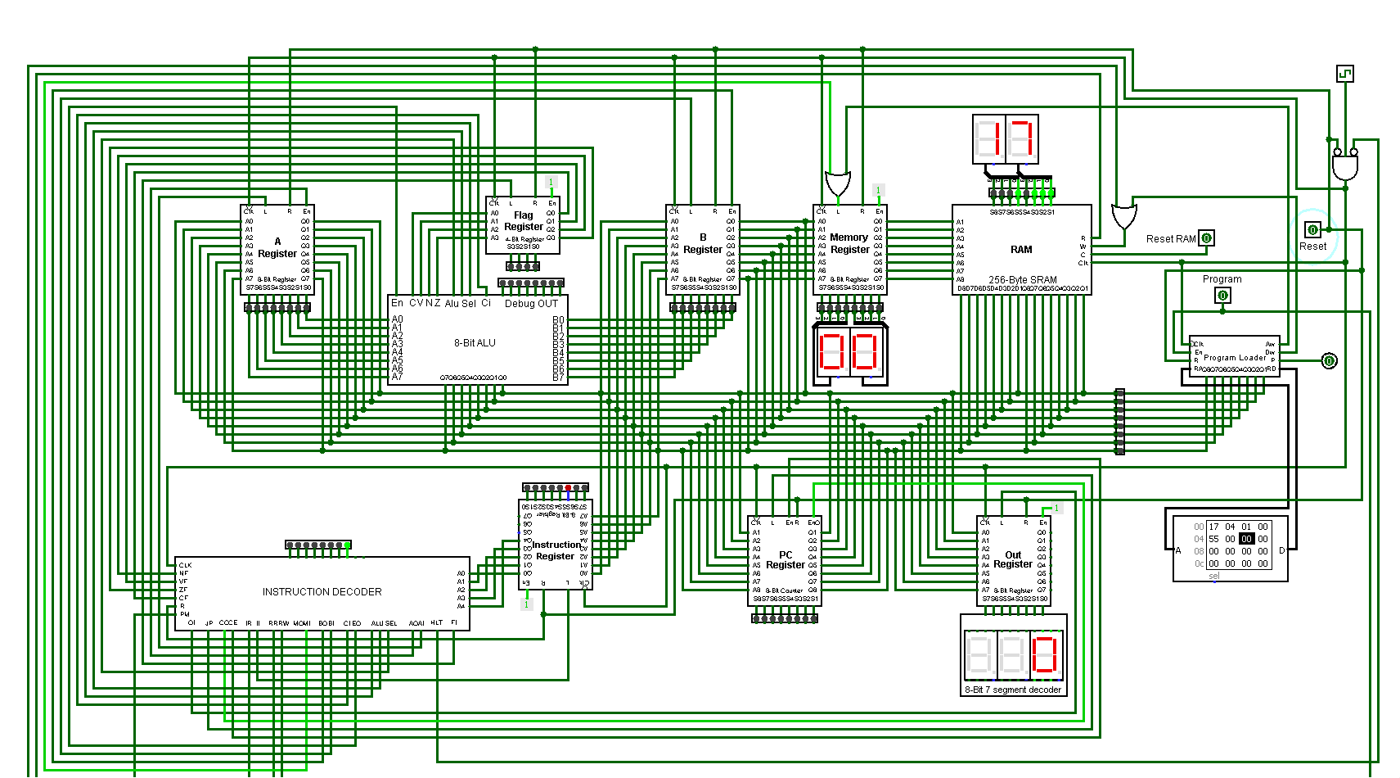
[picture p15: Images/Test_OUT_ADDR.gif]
OUT ADDR test


#### JMP [ADDR]
```nasm
JMP 0x20

# address 0x20
LDA 0x55
OUTA
HLT
```
```nasm
v2.0 raw
00: 18 10
...
10: 02 55
12: 14
13: 01
```
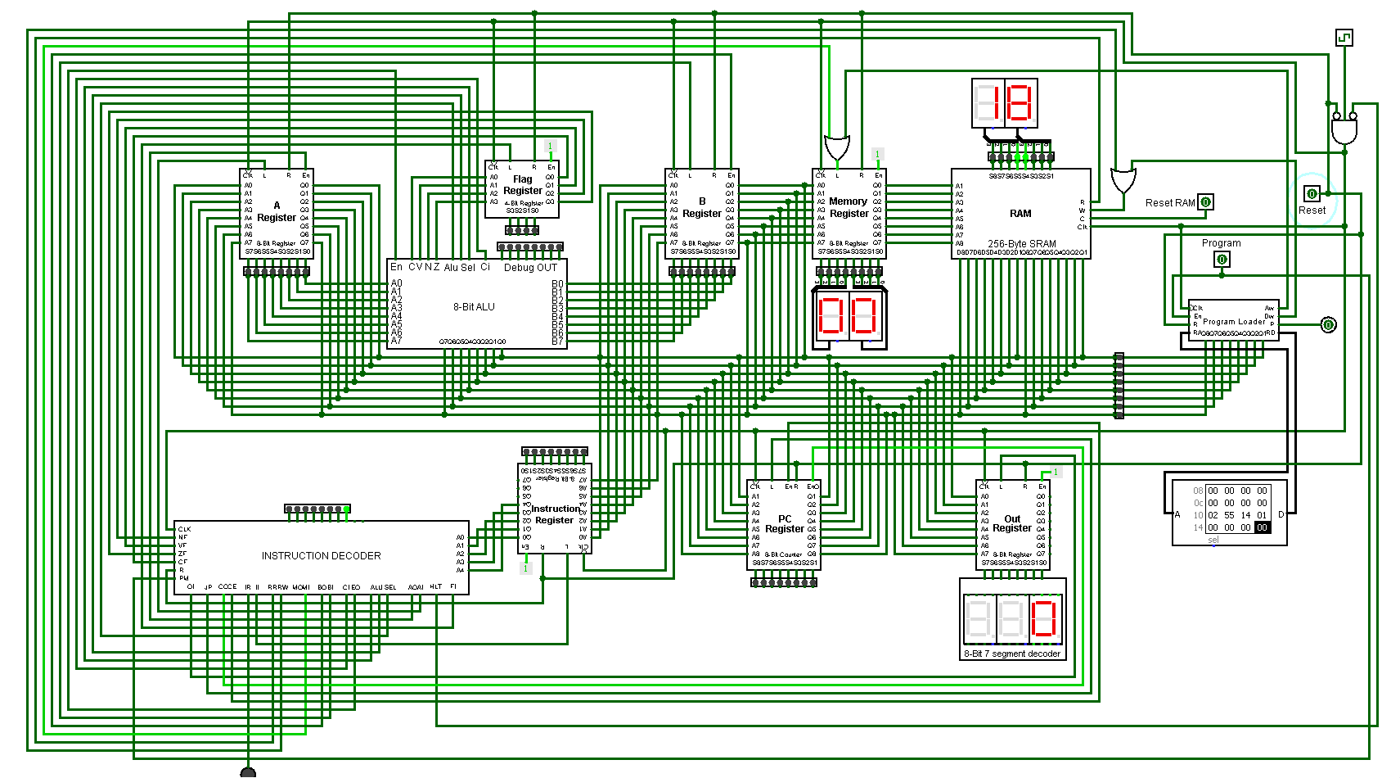
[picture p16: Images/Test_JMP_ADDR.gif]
JMP ADDR test


#### JPZ [ADDR]
ZF = 1
```nasm
00: LDA 0x04
02: SUB 0x04
04: JPZ 0x10
06: OUT 0xFF
07: HLT
...
10: OUT 0x55
12: HLT
```
```nasm
v2.0 raw
02 04
0a 04
19 10
16 ff
01
00 00
00 00
00 00
00
16 55
01
```
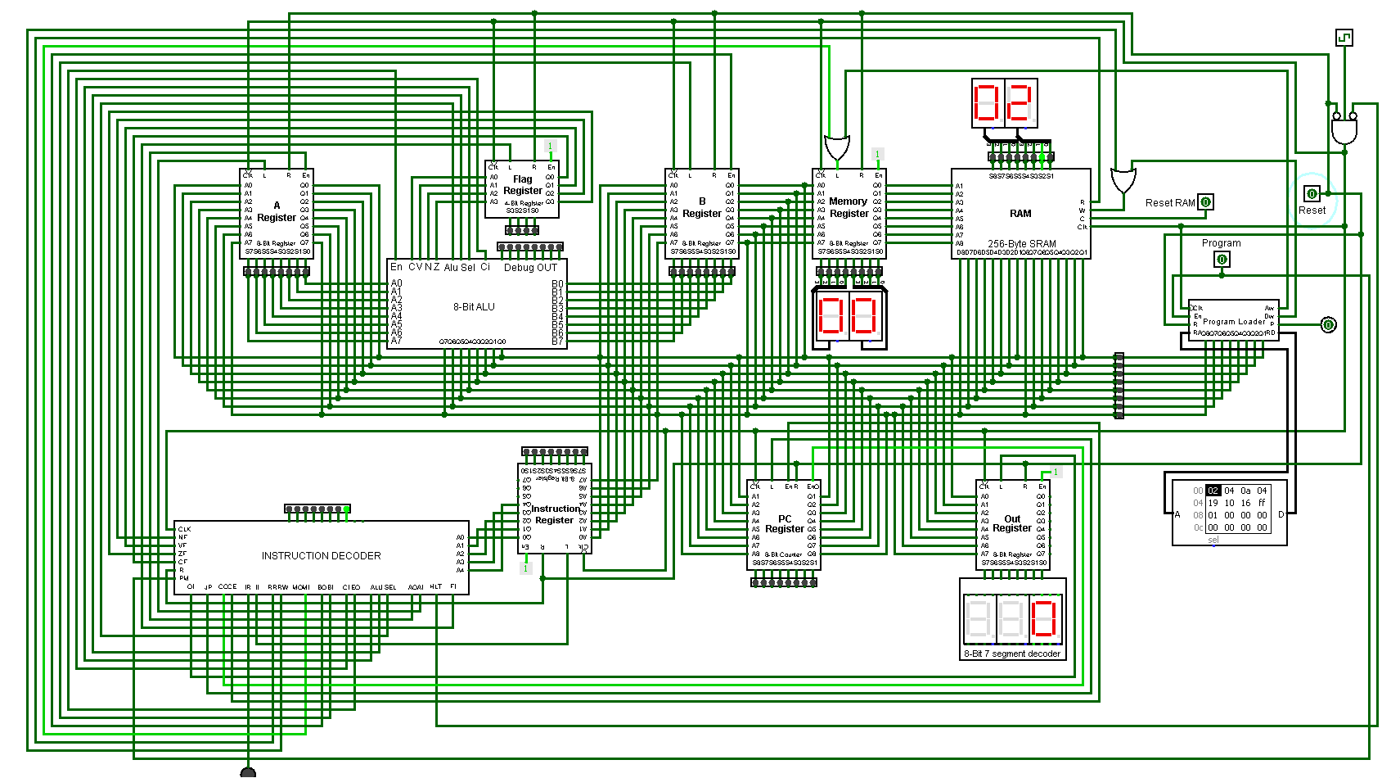
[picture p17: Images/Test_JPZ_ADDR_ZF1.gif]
JPZ ZF = 1 ADDR test


ZF = 0
```nasm
00: LDA 0x04
02: ADD 0x04
04: JPZ 0x10
06: OUT 0xFF
07: HLT
...
10: OUT 0x55
12: HLT
```
```nasm
v2.0 raw
02 04
0a 04
19 10
16 ff
01
00 00
00 00
00 00
00
16 55
01
```
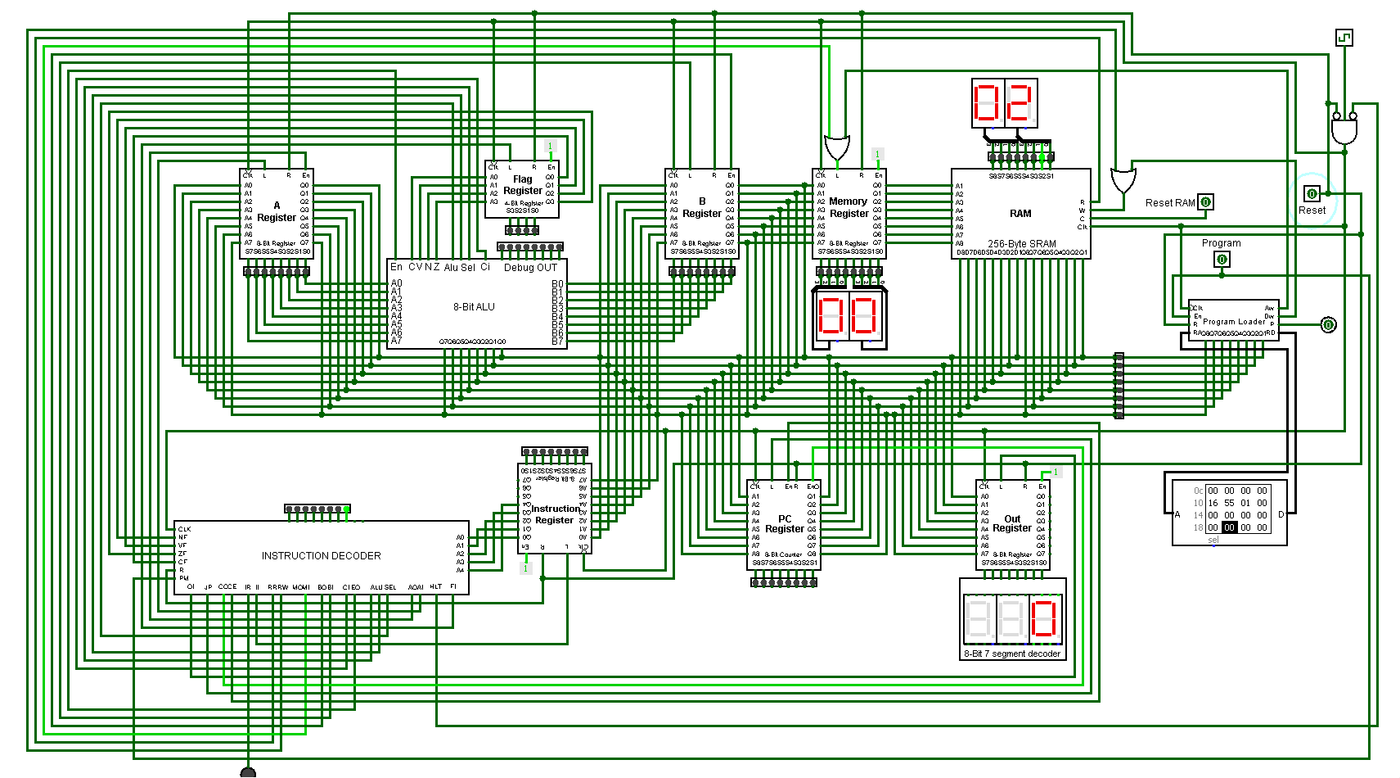
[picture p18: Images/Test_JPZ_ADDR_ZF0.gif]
JPZ ZF = 0 ADDR test


#### JPC [ADDR]
CF = 0
```nasm
00: LDA 0xFE
02: ADD 0x01
04: JPC 0x10
06: OUT 0xFF
07: HLT
...
10: OUT 0x55
12: HLT
```
```nasm
v2.0 raw
02 FE
08 01
1A 10
16 FF
01
00 00
00 00
00 00
00
16 55
01
```
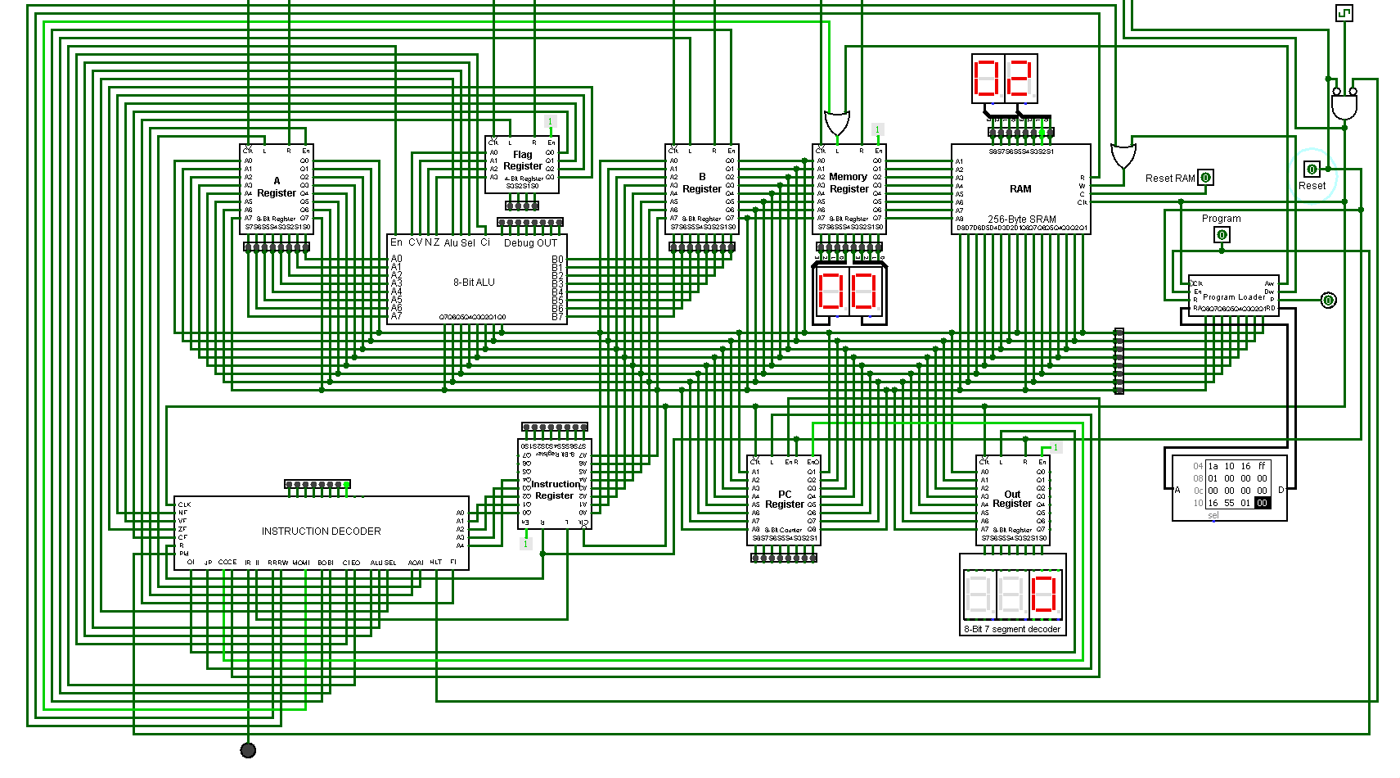
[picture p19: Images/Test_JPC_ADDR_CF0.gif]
JPC CF = 0 ADDR test


CF = 1
```nasm
00: LDA 0xFE
02: ADD 0x02
04: JPC 0x10
06: OUT 0xFF
07: HLT
...
10: OUT 0x55
12: HLT
```
```nasm
v2.0 raw
02 FE
08 02
1A 10
16 FF
01
00 00
00 00
00 00
00
16 55
01
```
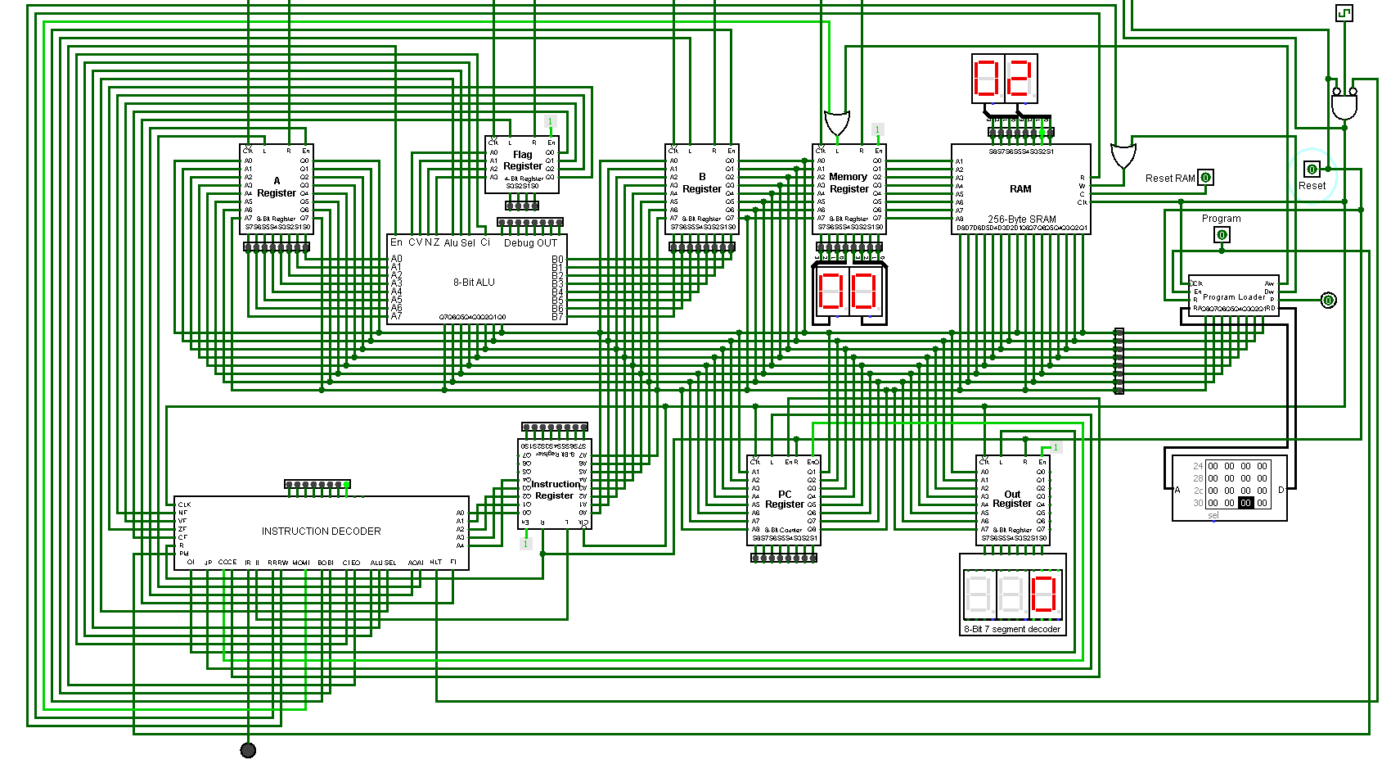
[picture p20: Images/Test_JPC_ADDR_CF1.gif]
JPC CF = 1 ADDR test


#### RST
```nasm
TODO
```
```nasm
v2.0 raw
```
RST test

#### Fibinacci test
```nasm
INIT:
00:  LDA 0X00
02:  STA [N1]
04:  OUT [N1]
06:  LDA 0X01
08:  STA [N2]
START:
0A  OUT [N2]
0C  LDA [N1]
0E  ADD [N2]
10  STB [N1]
12  STA [N2]
14  JPC [INIT]
16  JMP [START]
# 18: [N1]
# 19: [N2]
```
```nasm
v2.0 raw
02 00
04 18
17 18
02 01
04 19
17 19
03 18
09 19
07 18
04 19
1A 00
18 0A
```
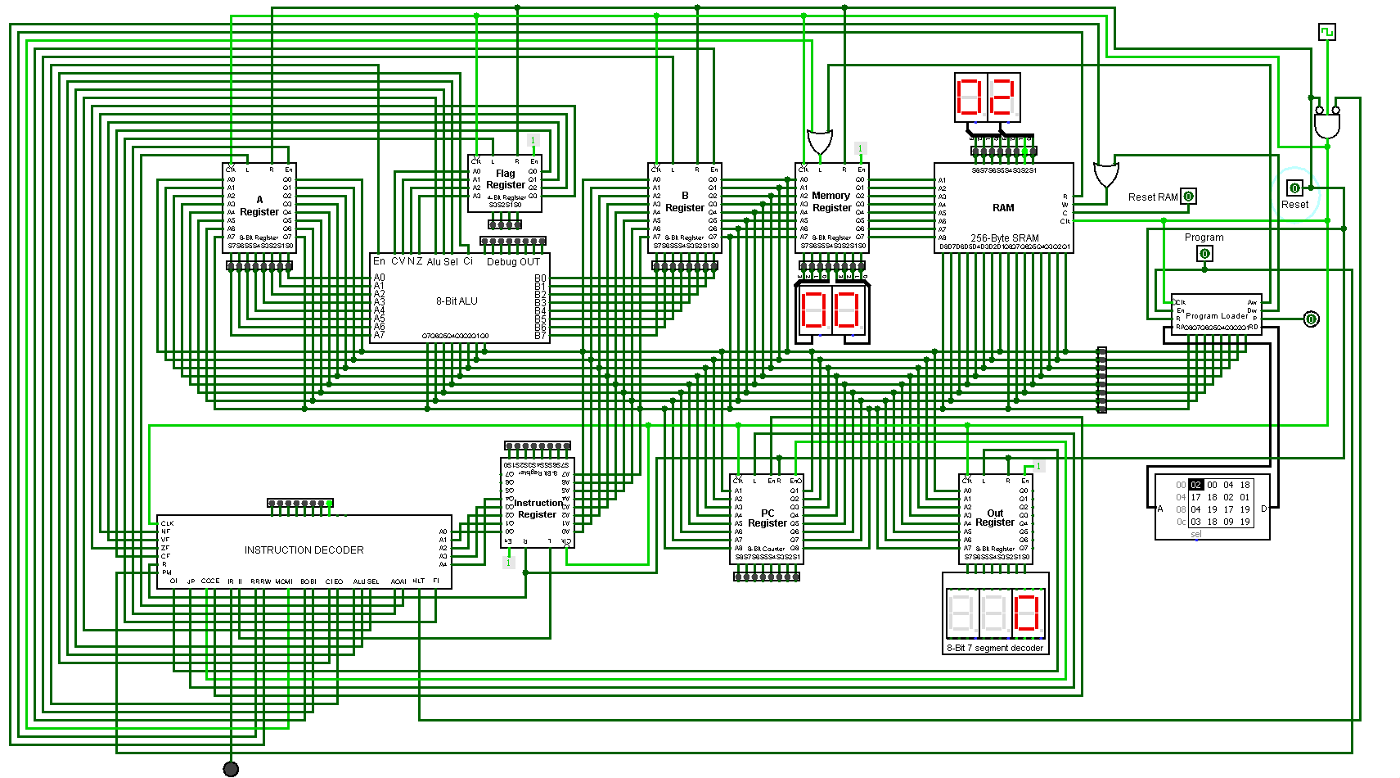
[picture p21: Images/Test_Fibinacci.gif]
Fibinacci test


#### Multiplication test
Reference code in C
```C
void multiply(uint8_t *result, uint8_t *multiplicand, uint8_t *multiplier) {
  uint8_t temp = 0;
  while (1) {
    if (*multiplier == 0) {
      break;
    }
    temp = *result;
    temp = temp + *multiplicand;
    *result = temp;

    temp = *multiplier;
    temp = temp - 1;
    *multiplier = temp;
  }

  printf("%d\n", *result);
  return;
}

int main(void) {
  uint8_t result = 0, multiplicand = 4, multiplier = 5;
  multiply(&result, &multiplicand, &multiplier);
}

```
```nasm
INIT:
0x00  LDA 4
0x02  STA [MULTIPLIER]
0x04  OUTA
0x05  LDA 0
0x07  STA [RESULT]
0x09  LDA 5
0x0B  STA [MULTIPLICAND]
0x0D  OUTA

START:
0x0E  JPZ [END]

0x10  LDA [RESULT]
0x12  ADD [MULTIPLICAND]
0x14  STA [RESULT]

0x16  LDA [MULTIPLIER]
0x18  SUB 1
0x1C  STA [MULTIPLIER]

0x1E  JP  [START]

END:
0x20  OUT [RESULT]
0x22  HALT

# 0x23  MULTIPLIER
# 0x24  MULTIPLICAND
# 0X25  RESULT
```
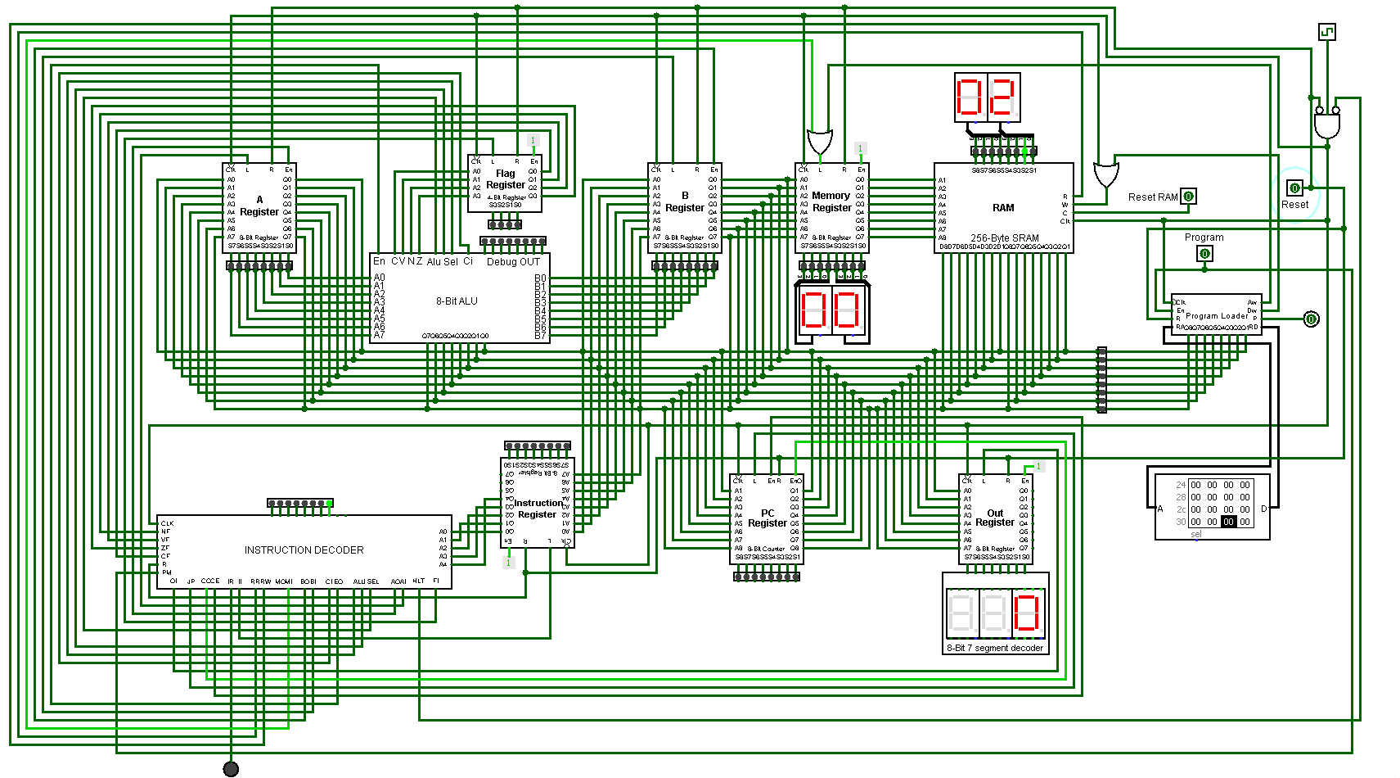
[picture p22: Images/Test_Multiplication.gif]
Multiplication test


## CPU Design

### Register
#### D-Flip Flop
<p align="center" width="100%">
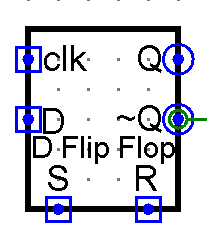
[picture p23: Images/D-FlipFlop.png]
D-FLip Flop with set and reset
  
</p>
<p align="center" width="100%">
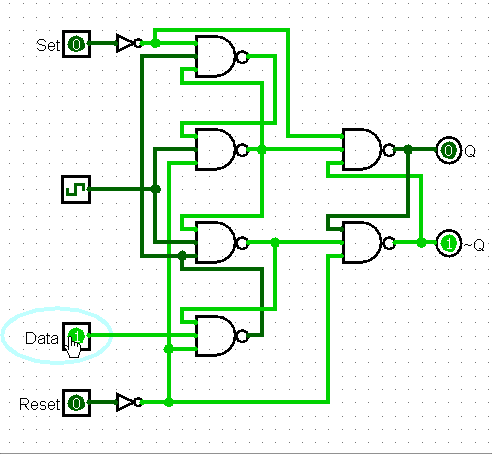
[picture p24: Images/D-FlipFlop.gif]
D-FLip Flop with set and reset GIF
  
</p>

D-Flip Flop will latch (save) whats in the input line (D) when the clock signal is on the rising edge into the output (Q) and it will store the invserse in output (Q').  Setting the set flag (S) to 1 will bypass the clock pulse and latch the output (Q) to 1 and the output (Q') to 0.  Setting the reset flag (R) to 1 will bypass the clock pulse and latch the output (Q) to a 0 and the output (Q') to a 1.

The initial state of the D-Flip Flops output pins (Q) and (Q') are unknown so setting an initial reset (R) is used to initialize the D-FLip Flop to 0(Q) and 1 (Q')

Inputs
- **Clock** - Clock pulse
- **Data** - Data to latch
- **Set** - Hold output Q to 1
- **Reset** - Hold output Q to 0

Outputs
- **Q** - Latched data
- **Q'** - Inverse of latched data

Truth Table
| Clock | D | S | R | Q | Q' |
|---|---|---|---|---|----|
|0 |X  |0  |0  |Q  |Q'  |
|0 |X  |1  |0  |1  |0 |
|0 |X  |0  |1  |0  |1 |
|1 |0  |0  |0  |0  |1 |
|1 |0  |0  |1  |0  |1 |
|1 |0  |1  |0  |1  |0 |
|1 |1  |0  |1  |0  |1 |
|1 |1  |1  |0  |1  |0 |
|1 |1  |0  |0  |1  |0 |
|1 |X  |1  |1  |1  |ERR |

#### 1-Bit register
<p align="center" width="100%">
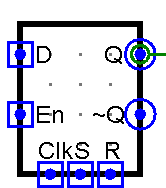
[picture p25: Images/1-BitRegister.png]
1-Bit register
  
</p>

<p align="center" width="100%">
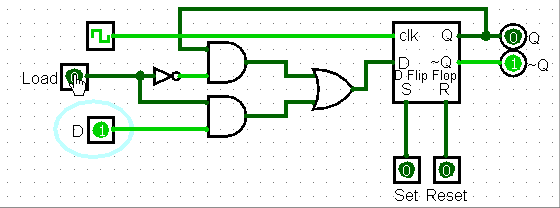
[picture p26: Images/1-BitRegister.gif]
1-Bit register
  
</p>

The 1-Bit register is made up of 1 D-Flip Flop. There is extra logic that will load the output (Q) back into the input (D) when a clock pulse comes in. This is to keep the same value latched each pulse of the clock if the load pin is not active.

Inputs
- **Clock** - Clock pulse
- **Load** - Enable pin to load the input data into the circuit
- **Data** - Data to latch
- **Set** - Hold output Q to 1
- **Reset** - Hold output Q to 0

Outputs
- **Q** - Latched data
- **Q'** - Inverse of latched data

#### 4-Bit register
Identical to the 8-Bit register but with 4 input and output pins instead of 8

#### 8-Bit register
<p align="center" width="100%">
  8-Bit register
</p>

<p align="center" width="100%">
  8-Bit register
</p>

The 8-Bit register is made up of 8 1-Bit registers. There is an aditional enable pin used to enable the output pins Q1:Q7. Q'1:Q'7 are not currently routed to output pins.

Inputs
- **Clock** - Clock pulse
- **Load** - Enable pin to load the input data into the circuit
- **Data A1:A7** - Data to latch
- **Set** - Hold output Q to 1
- **Reset** - Hold output Q to 0
- **Enable** - Enables output pins

Outputs
- **S1:S7** - Imediate data latched.
- **Q1:Q7** - Latched data
- **Q'1:Q'7** - Inverse of latched data (Not routed to output pins)

#### Available registers in this project

- Program counter register (PC)
  - The program counter is a register that contains the address
  of the instruction being executed at the current time. As each instruction gets fetched, the program counter increases its stored value by 1. After each instruction is fetched, the program counter points to the next instruction in the sequence. The program counter register is built using 8 J-K Flip Flops linked together.

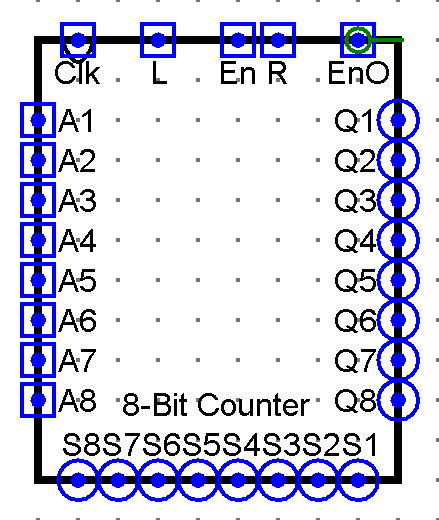
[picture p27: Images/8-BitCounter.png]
8-Bit counter reference
  

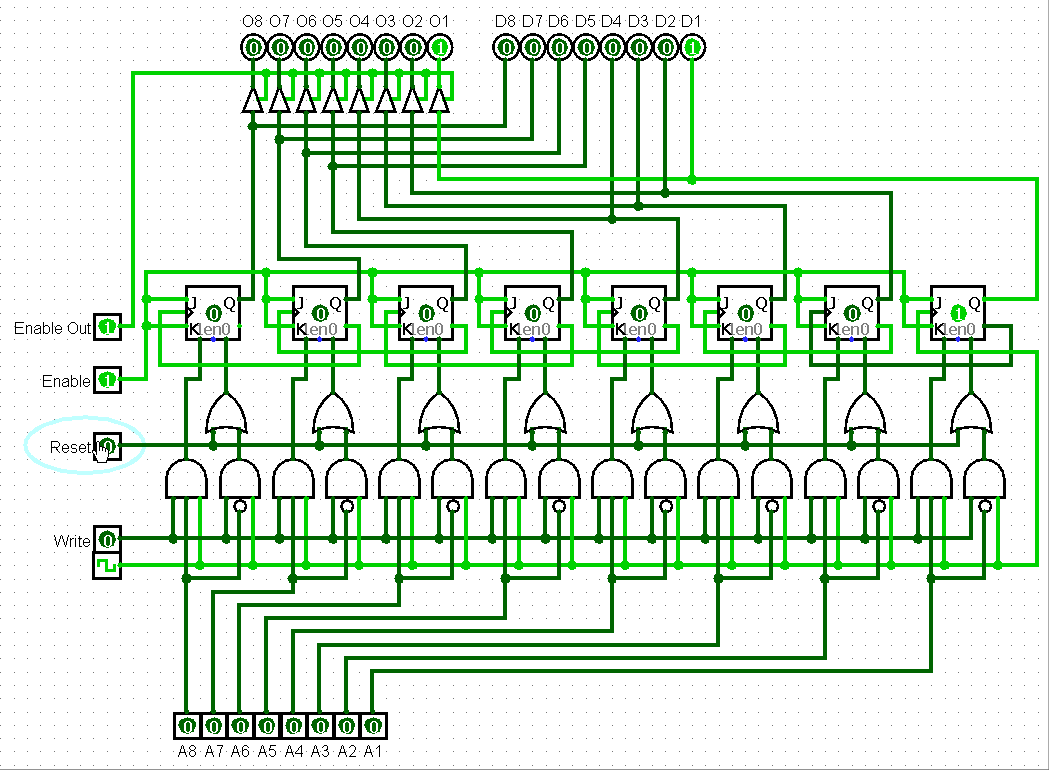
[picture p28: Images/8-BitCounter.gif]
8-Bit counter reference
  

  Inputs
  - **Enable Out[EnO]** - Enables the output pins
  - **Enable[En]** - Enables the counter
  - **Reset[R]** - Resets the counter back to 0
  - **Write[L]** - Write the input value A0:A8 to the current count value.
  - **Clock[Clk]** - Clock pulse
  - **A1:A8** - Data input, used to set the current count value.

  Outputs
  - **Q1:Q8** - Data output pins.
  - **S1:S8** - Imediate data outputs.

- Register A connected to the ALU
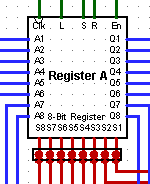
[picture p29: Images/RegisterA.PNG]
A register
  - 
  - General purpose register connected directly to the ALU
- Register B connected to the ALU
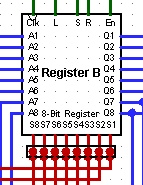
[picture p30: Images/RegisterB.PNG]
B register
  - 
  - General purpose register connected directly to the ALU
- Instruction register
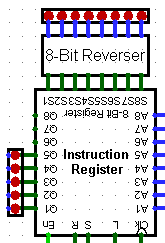
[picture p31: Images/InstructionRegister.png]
Instruction register
  - 
  - The instruction register holds a machine instruction that is currently being executed.  It remains in the instruction register until the instruction decoder is finished executing the micro-instructions.
- memory address register
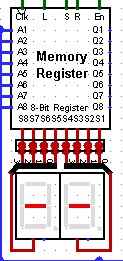
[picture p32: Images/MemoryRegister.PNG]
Memory register
  - 
  - This reigster is directly connected to the RAM and stores the address to read/write from.
- output register
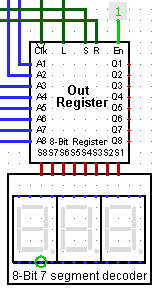
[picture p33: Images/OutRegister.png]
Output register
  - 
  - General purpose register connected to the data bus. Stores the output data from any operation.
- Status flags register
  - Flags Register
  - Contains the ALU status flags Z(Zero), V(overflow), N(negative), C(carry)

### Half Adder
### Full Adder
### 8-Bit Adder
### D-Latch
### 4-Bit Binary Decoder
### Multiplexer
#### 1-Bit Multiplexer
#### 8-Bit Multiplexer
#### 8-Bit 2x1 Multiplexer
#### 8-Bit 4x1 Multiplexer
### 8-Bit Clear
### 8-Bit Inverter
### 8-Bit OR
### 8-Bit AND
### 8-Bit XOR
### 8-Bit ALU
### 4-Bit Decoder - 7 Segment
### 8-Bit Decoder - 7 Segment
### 8-Bit Reverser
### SRAM
#### 16-Byte SRAM
#### 256-Byte SRAM
### Program Loader
### 8-Bit Processor

## Assembler
[Assembler source](Assembler/)

### Building
Compile assembler with
```make```

Compile google test unit tests with
```make test```

Compile assembler and unit tests with
```make all```

Execute unit tests and generate coverage report with
```make coverage```

Clean the build with
```make clean```

### Number formats
The assembler support the following number formats:
- ```100``` Decimal
- ```100d``` Explicit decimal
- ```0xAA``` Hexadecimal
- ```0o20``` Octal
- ```011b``` Binary

### Label formats
Labels can be on their own line or inline with code:
```
INIT: lda 21
      outa
Variable: db 0
```
```
INIT:
    lda [variable]
    outa
variable:
    db 0
```
### Instruction formats
All instructions/labels are not case sensitive.

### Output files
```a.hex``` Is a raw hex output for loading into logisim
```a.bin``` Is a standard binary output format.

### Example output
```
Assembling example.asm
Warning: 0 references found for label 'END' on line 16
Address   Compiled    Raw
  0:      02 00       LDA 00
  2:      04 19       STA [N1]
  4:      17 19       OUT [N1]
  6:      02 01       LDA 01
  8:      04 1A       STA [N2]
  A:      17 1A       OUT [N2]
  C:      03 19       LDA [N1]
  E:      09 1A       ADD [N2]
 10:      07 19       STB [N1]
 12:      04 1A       STA [N2]
 14:      1A 00       JPC [INIT]
 16:      18 0A       JMP [START]
 18:      01          HLT
 19:      00          N1: DB 00
 1A:      00          N2: DB 00
 ```

### Warnings & Errors
```
Error: line 1 Syntax error too many ':' in label - INI:T:
```
Fix: Fix the label formatting by removing the extra ':' ```INIT:```.
```
Error: Line 2 duplicate label found 'variable' first referenced on line 1
```
Fix: Remove the duplicate label on line 2.
```
Error: line 1 Operand missing - LDA
```
Fix: OpCode requires an operand ```LDA NUM or LDA [addr]```.
```
Error: line 1 Invalid number format - LDA a342
```
Fix: Fix the improper number format by removing the 'a' ```LDA 342```.
```
Error: line 1 Number '300' exceeds 8 bit max 255 - LDA 300
```
Fix: Value exceeds an 8 bit max value, reduce to within range ```LDA 255```.
```
Error: line 1 Instruction HLT does not support operands - HLT 23
```
Fix: Remove the operand from the instruction ```HLT```.
```
Error: line 1 Missing variable initializer - variable: DB
```
Fix: Add default initializer to the label variable ```variable: DB 0```.
```
Warning: 0 references found for label 'variable' on line 7
```
Fix: Variable label is not referenced in code, remove it or reference it.

### Reference assembler outputs.
Example asm program
```asm
          global    _start

          section   .text
_start:   mov       rax, 1                  ; system call for write
          mov       rdi, 1                  ; file handle 1 is stdout
          mov       rsi, message            ; address of string to output
          mov       rdx, 13                 ; number of bytes
          syscall                           ; invoke operating system to do the write
          mov       rax, 60                 ; system call for exit
          xor       rdi, rdi                ; exit code 0
          syscall                           ; invoke operating system to exit

          section   .data
message:  db        "Hello, World", 10      ; note the newline at the end
```
objdump -D
```asm
Disassembly of section .text:

0000000000000000 <_start>:
   0:   b8 01 00 00 00          mov    $0x1,%eax
   5:   bf 01 00 00 00          mov    $0x1,%edi
   a:   48 be 00 00 00 00 00    movabs $0x0,%rsi
  11:   00 00 00
  14:   ba 0d 00 00 00          mov    $0xd,%edx
  19:   0f 05                   syscall
  1b:   b8 3c 00 00 00          mov    $0x3c,%eax
  20:   48 31 ff                xor    %rdi,%rdi
  23:   0f 05                   syscall

Disassembly of section .data:

0000000000000000 <message>:
   0:   48                      rex.W
   1:   65 6c                   gs insb (%dx),%es:(%rdi)
   3:   6c                      insb   (%dx),%es:(%rdi)
   4:   6f                      outsl  %ds:(%rsi),(%dx)
   5:   2c 20                   sub    $0x20,%al
   7:   57                      push   %rdi
   8:   6f                      outsl  %ds:(%rsi),(%dx)
   9:   72 6c                   jb     77 <message+0x77>
   b:   64                      fs
   c:   0a                      .byte 0xa
```
objdump -s
```asm
Contents of section .text:
 0000 b8010000 00bf0100 000048be 00000000  ..........H.....
 0010 00000000 ba0d0000 000f05b8 3c000000  ............<...
 0020 4831ff0f 05                          H1...
Contents of section .data:
 0000 48656c6c 6f2c2057 6f726c64 0a        Hello, World.
```
diff between pre and post linked object file
```asm
asm.o:     file format elf64-x86-64                           | a.out:     file format elf64-x86-64

Disassembly of section .text:                                   Disassembly of section .text:

0000000000000000 <_start>:                                    | 0000000000401000 <_start>:
   0:   b8 01 00 00 00          mov    $0x1,%eax              |   401000:       b8 01 00 00 00          mov    $0x1,%eax
   5:   bf 01 00 00 00          mov    $0x1,%edi              |   401005:       bf 01 00 00 00          mov    $0x1,%edi
   a:   48 be 00 00 00 00 00    movabs $0x0,%rsi              |   40100a:       48 be 00 20 40 00 00    movabs $0x402000,%rsi
  11:   00 00 00                                              |   401011:       00 00 00
  14:   ba 0d 00 00 00          mov    $0xd,%edx              |   401014:       ba 0d 00 00 00          mov    $0xd,%edx
  19:   0f 05                   syscall                       |   401019:       0f 05                   syscall
  1b:   b8 3c 00 00 00          mov    $0x3c,%eax             |   40101b:       b8 3c 00 00 00          mov    $0x3c,%eax
  20:   48 31 ff                xor    %rdi,%rdi              |   401020:       48 31 ff                xor    %rdi,%rdi
  23:   0f 05                   syscall                       |   401023:       0f 05                   syscall
```
elf header dump
```asm
ELF Header:
  Magic:   7f 45 4c 46 02 01 01 00 00 00 00 00 00 00 00 00
  Class:                             ELF64
  Data:                              2's complement, little endian
  Version:                           1 (current)
  OS/ABI:                            UNIX - System V
  ABI Version:                       0
  Type:                              EXEC (Executable file)
  Machine:                           Advanced Micro Devices X86-64
  Version:                           0x1
  Entry point address:               0x401000
  Start of program headers:          64 (bytes into file)
  Start of section headers:          8464 (bytes into file)
  Flags:                             0x0
  Size of this header:               64 (bytes)
  Size of program headers:           56 (bytes)
  Number of program headers:         3
  Size of section headers:           64 (bytes)
  Number of section headers:         6
  Section header string table index: 5
  ```
## Objdump
 TODO

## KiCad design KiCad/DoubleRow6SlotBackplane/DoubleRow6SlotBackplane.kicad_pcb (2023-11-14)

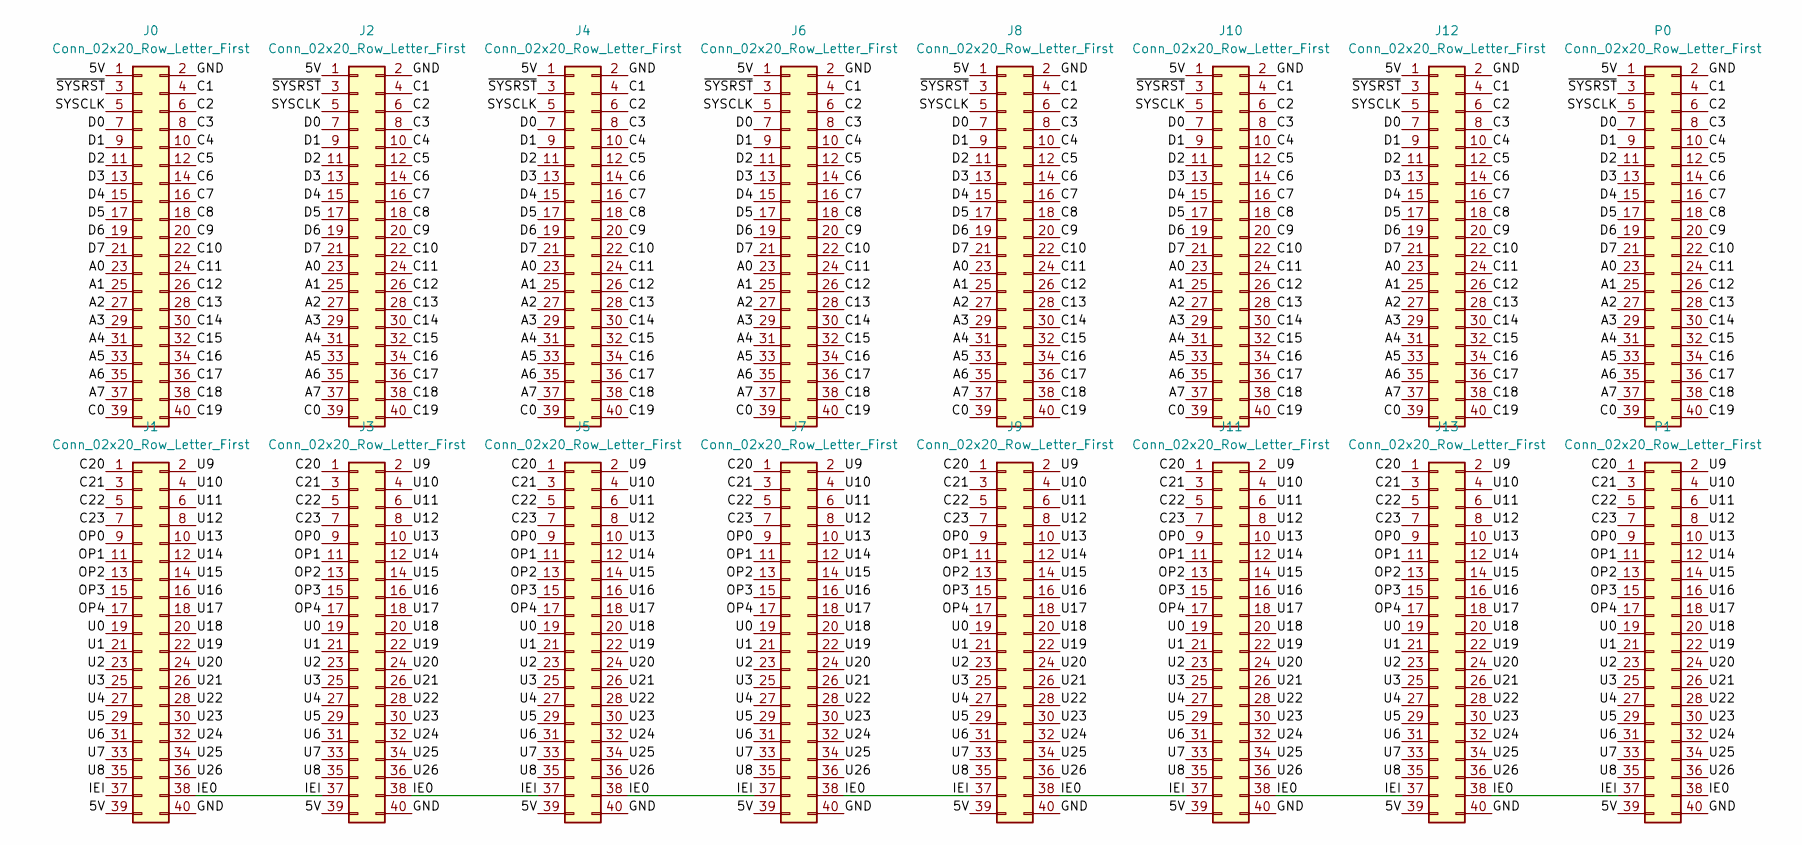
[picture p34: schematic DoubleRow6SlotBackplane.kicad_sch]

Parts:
J0, J1: Conn_02x20_Row_Letter_First; PinSocket_2x20_P2.54mm_Horizontal
J2, J3, J4, J5, J6, J7, J8, J9, J10, J11, J12, J13: Conn_02x20_Row_Letter_First; PinSocket_2x20_P2.54mm_Vertical
P0, P1: Conn_02x20_Row_Letter_First; PinHeader_2x20_P2.54mm_Horizontal

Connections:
/5V: J0.1, J1.39, J2.1, J3.39, J4.1, J5.39, J6.1, J7.39, J8.1, J9.39, J10.1, J11.39, J12.1, J13.39, P0.1, P1.39
/A0: J0.23, J2.23, J4.23, J6.23, J8.23, J10.23, J12.23, P0.23
/A1: J0.25, J2.25, J4.25, J6.25, J8.25, J10.25, J12.25, P0.25
/A2: J0.27, J2.27, J4.27, J6.27, J8.27, J10.27, J12.27, P0.27
/A3: J0.29, J2.29, J4.29, J6.29, J8.29, J10.29, J12.29, P0.29
/A4: J0.31, J2.31, J4.31, J6.31, J8.31, J10.31, J12.31, P0.31
/A5: J0.33, J2.33, J4.33, J6.33, J8.33, J10.33, J12.33, P0.33
/A6: J0.35, J2.35, J4.35, J6.35, J8.35, J10.35, J12.35, P0.35
/A7: J0.37, J2.37, J4.37, J6.37, J8.37, J10.37, J12.37, P0.37
/C0: J0.39, J2.39, J4.39, J6.39, J8.39, J10.39, J12.39, P0.39
/C1: J0.4, J2.4, J4.4, J6.4, J8.4, J10.4, J12.4, P0.4
/C2: J0.6, J2.6, J4.6, J6.6, J8.6, J10.6, J12.6, P0.6
/C3: J0.8, J2.8, J4.8, J6.8, J8.8, J10.8, J12.8, P0.8
/C4: J0.10, J2.10, J4.10, J6.10, J8.10, J10.10, J12.10, P0.10
/C5: J0.12, J2.12, J4.12, J6.12, J8.12, J10.12, J12.12, P0.12
/C6: J0.14, J2.14, J4.14, J6.14, J8.14, J10.14, J12.14, P0.14
/C7: J0.16, J2.16, J4.16, J6.16, J8.16, J10.16, J12.16, P0.16
/C8: J0.18, J2.18, J4.18, J6.18, J8.18, J10.18, J12.18, P0.18
/C9: J0.20, J2.20, J4.20, J6.20, J8.20, J10.20, J12.20, P0.20
/C10: J0.22, J2.22, J4.22, J6.22, J8.22, J10.22, J12.22, P0.22
/C11: J0.24, J2.24, J4.24, J6.24, J8.24, J10.24, J12.24, P0.24
/C12: J0.26, J2.26, J4.26, J6.26, J8.26, J10.26, J12.26, P0.26
/C13: J0.28, J2.28, J4.28, J6.28, J8.28, J10.28, J12.28, P0.28
/C14: J0.30, J2.30, J4.30, J6.30, J8.30, J10.30, J12.30, P0.30
/C15: J0.32, J2.32, J4.32, J6.32, J8.32, J10.32, J12.32, P0.32
/C16: J0.34, J2.34, J4.34, J6.34, J8.34, J10.34, J12.34, P0.34
/C17: J0.36, J2.36, J4.36, J6.36, J8.36, J10.36, J12.36, P0.36
/C18: J0.38, J2.38, J4.38, J6.38, J8.38, J10.38, J12.38, P0.38
/C19: J0.40, J2.40, J4.40, J6.40, J8.40, J10.40, J12.40, P0.40
/C20: J1.1, J3.1, J5.1, J7.1, J9.1, J11.1, J13.1, P1.1
/C21: J1.3, J3.3, J5.3, J7.3, J9.3, J11.3, J13.3, P1.3
/C22: J1.5, J3.5, J5.5, J7.5, J9.5, J11.5, J13.5, P1.5
/C23: J1.7, J3.7, J5.7, J7.7, J9.7, J11.7, J13.7, P1.7
/D0: J0.7, J2.7, J4.7, J6.7, J8.7, J10.7, J12.7, P0.7
/D1: J0.9, J2.9, J4.9, J6.9, J8.9, J10.9, J12.9, P0.9
/D2: J0.11, J2.11, J4.11, J6.11, J8.11, J10.11, J12.11, P0.11
/D3: J0.13, J2.13, J4.13, J6.13, J8.13, J10.13, J12.13, P0.13
/D4: J0.15, J2.15, J4.15, J6.15, J8.15, J10.15, J12.15, P0.15
/D5: J0.17, J2.17, J4.17, J6.17, J8.17, J10.17, J12.17, P0.17
/D6: J0.19, J2.19, J4.19, J6.19, J8.19, J10.19, J12.19, P0.19
/D7: J0.21, J2.21, J4.21, J6.21, J8.21, J10.21, J12.21, P0.21
/GND: J0.2, J1.40, J2.2, J3.40, J4.2, J5.40, J6.2, J7.40, J8.2, J9.40, J10.2, J11.40, J12.2, J13.40, P0.2, P1.40
/IE0: J1.37, J1.38, J3.37, J3.38, J5.37, J5.38, J7.37, J7.38, J9.37, J9.38, J11.37, J11.38, J13.37, J13.38, P1.37, P1.38
/OP0: J1.9, J3.9, J5.9, J7.9, J9.9, J11.9, J13.9, P1.9
/OP1: J1.11, J3.11, J5.11, J7.11, J9.11, J11.11, J13.11, P1.11
/OP2: J1.13, J3.13, J5.13, J7.13, J9.13, J11.13, J13.13, P1.13
/OP3: J1.15, J3.15, J5.15, J7.15, J9.15, J11.15, J13.15, P1.15
/OP4: J1.17, J3.17, J5.17, J7.17, J9.17, J11.17, J13.17, P1.17
/SYSCLK: J0.5, J2.5, J4.5, J6.5, J8.5, J10.5, J12.5, P0.5
/U0: J1.19, J3.19, J5.19, J7.19, J9.19, J11.19, J13.19, P1.19
/U1: J1.21, J3.21, J5.21, J7.21, J9.21, J11.21, J13.21, P1.21
/U2: J1.23, J3.23, J5.23, J7.23, J9.23, J11.23, J13.23, P1.23
/U3: J1.25, J3.25, J5.25, J7.25, J9.25, J11.25, J13.25, P1.25
/U4: J1.27, J3.27, J5.27, J7.27, J9.27, J11.27, J13.27, P1.27
/U5: J1.29, J3.29, J5.29, J7.29, J9.29, J11.29, J13.29, P1.29
/U6: J1.31, J3.31, J5.31, J7.31, J9.31, J11.31, J13.31, P1.31
/U7: J1.33, J3.33, J5.33, J7.33, J9.33, J11.33, J13.33, P1.33
/U8: J1.35, J3.35, J5.35, J7.35, J9.35, J11.35, J13.35, P1.35
/U9: J1.2, J3.2, J5.2, J7.2, J9.2, J11.2, J13.2, P1.2
/U10: J1.4, J3.4, J5.4, J7.4, J9.4, J11.4, J13.4, P1.4
/U11: J1.6, J3.6, J5.6, J7.6, J9.6, J11.6, J13.6, P1.6
/U12: J1.8, J3.8, J5.8, J7.8, J9.8, J11.8, J13.8, P1.8
/U13: J1.10, J3.10, J5.10, J7.10, J9.10, J11.10, J13.10, P1.10
/U14: J1.12, J3.12, J5.12, J7.12, J9.12, J11.12, J13.12, P1.12
/U15: J1.14, J3.14, J5.14, J7.14, J9.14, J11.14, J13.14, P1.14
/U16: J1.16, J3.16, J5.16, J7.16, J9.16, J11.16, J13.16, P1.16
/U17: J1.18, J3.18, J5.18, J7.18, J9.18, J11.18, J13.18, P1.18
/U18: J1.20, J3.20, J5.20, J7.20, J9.20, J11.20, J13.20, P1.20
/U19: J1.22, J3.22, J5.22, J7.22, J9.22, J11.22, J13.22, P1.22
/U20: J1.24, J3.24, J5.24, J7.24, J9.24, J11.24, J13.24, P1.24
/U21: J1.26, J3.26, J5.26, J7.26, J9.26, J11.26, J13.26, P1.26
/U22: J1.28, J3.28, J5.28, J7.28, J9.28, J11.28, J13.28, P1.28
/U23: J1.30, J3.30, J5.30, J7.30, J9.30, J11.30, J13.30, P1.30
/U24: J1.32, J3.32, J5.32, J7.32, J9.32, J11.32, J13.32, P1.32
/U25: J1.34, J3.34, J5.34, J7.34, J9.34, J11.34, J13.34, P1.34
/U26: J1.36, J3.36, J5.36, J7.36, J9.36, J11.36, J13.36, P1.36
/~SYSRST: J0.3, J2.3, J4.3, J6.3, J8.3, J10.3, J12.3, P0.3

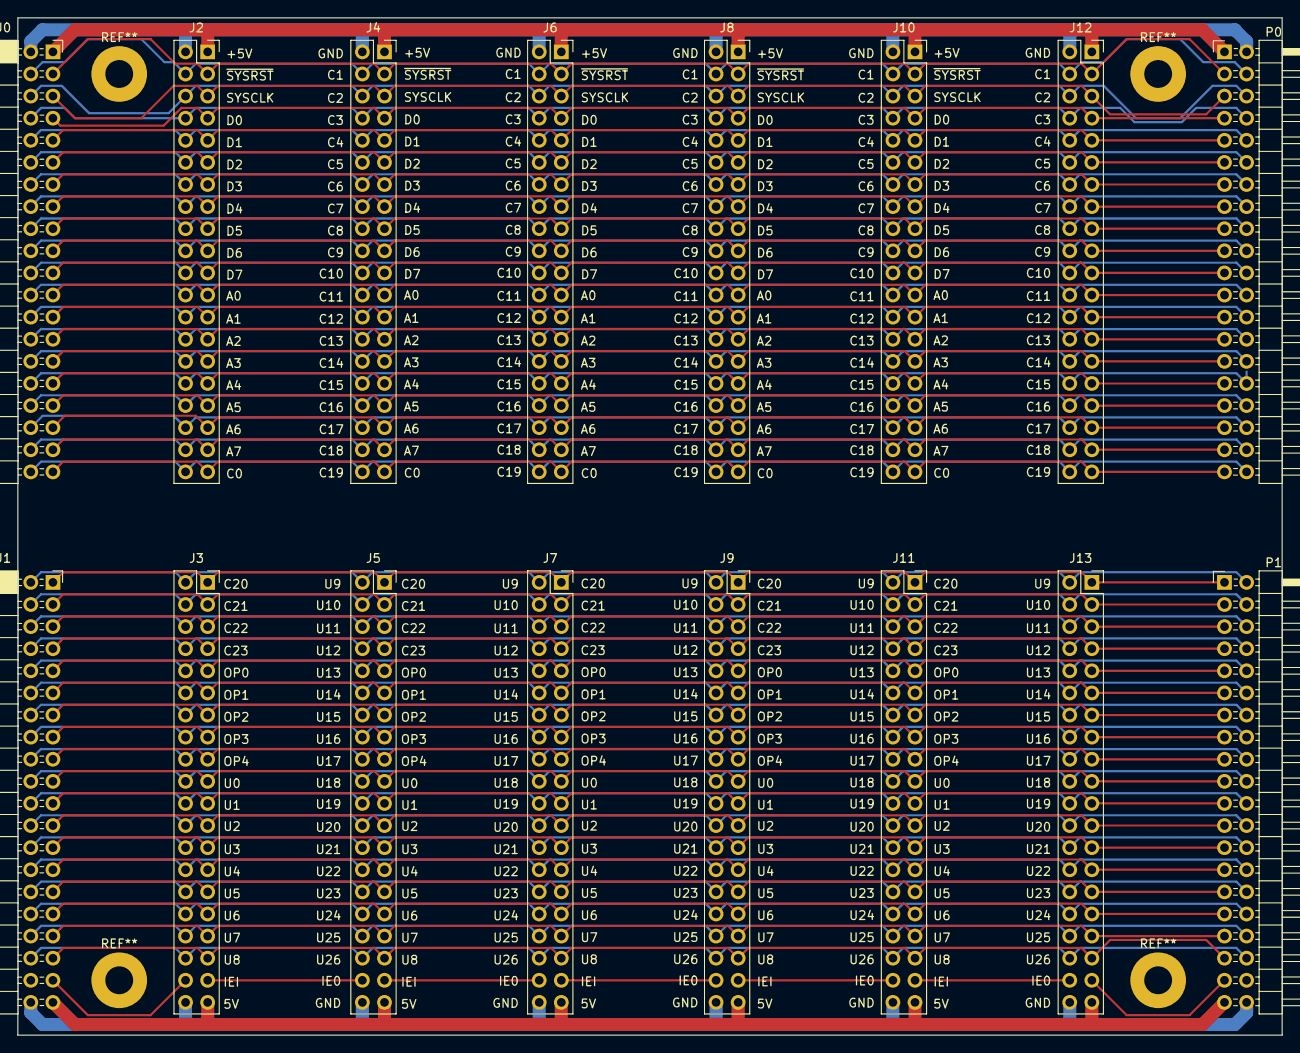
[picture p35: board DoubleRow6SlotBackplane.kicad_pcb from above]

Board: 2 copper layers, 145.3 x 116.9 mm, 16 parts (0 on the bottom side), 77 nets.

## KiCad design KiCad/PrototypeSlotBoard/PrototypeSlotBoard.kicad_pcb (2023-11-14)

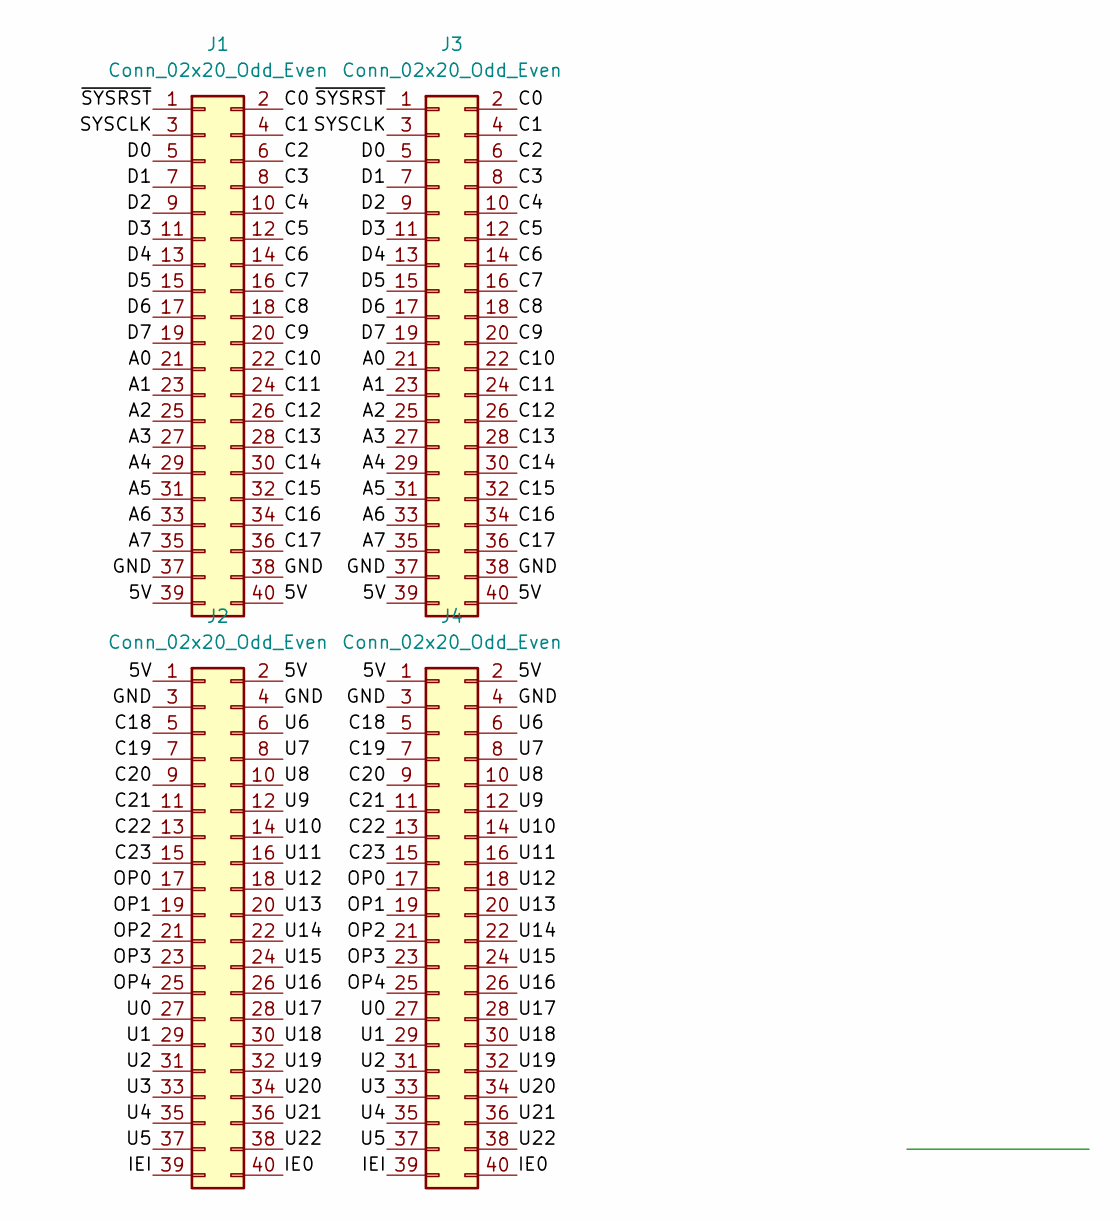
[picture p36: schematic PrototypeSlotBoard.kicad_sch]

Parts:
J1, J2: Conn_02x20_Odd_Even; PinHeader_2x20_P2.54mm_Horizontal
J3, J4: Conn_02x20_Odd_Even; PinHeader_2x20_P2.54mm_Vertical

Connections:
/5V: J1.39, J1.40, J2.1, J2.2, J3.39, J3.40, J4.1, J4.2
/A0: J1.21, J3.21
/A1: J1.23, J3.23
/A2: J1.25, J3.25
/A3: J1.27, J3.27
/A4: J1.29, J3.29
/A5: J1.31, J3.31
/A6: J1.33, J3.33
/A7: J1.35, J3.35
/C0: J1.2, J3.2
/C1: J1.4, J3.4
/C2: J1.6, J3.6
/C3: J1.8, J3.8
/C4: J1.10, J3.10
/C5: J1.12, J3.12
/C6: J1.14, J3.14
/C7: J1.16, J3.16
/C8: J1.18, J3.18
/C9: J1.20, J3.20
/C10: J1.22, J3.22
/C11: J1.24, J3.24
/C12: J1.26, J3.26
/C13: J1.28, J3.28
/C14: J1.30, J3.30
/C15: J1.32, J3.32
/C16: J1.34, J3.34
/C17: J1.36, J3.36
/C18: J2.5, J4.5
/C19: J2.7, J4.7
/C20: J2.9, J4.9
/C21: J2.11, J4.11
/C22: J2.13, J4.13
/C23: J2.15, J4.15
/D0: J1.5, J3.5
/D1: J1.7, J3.7
/D2: J1.9, J3.9
/D3: J1.11, J3.11
/D4: J1.13, J3.13
/D5: J1.15, J3.15
/D6: J1.17, J3.17
/D7: J1.19, J3.19
/GND: J1.37, J1.38, J2.3, J2.4, J3.37, J3.38, J4.3, J4.4
/IE0: J2.40, J4.40
/IEI: J2.39, J4.39
/OP0: J2.17, J4.17
/OP1: J2.19, J4.19
/OP2: J2.21, J4.21
/OP3: J2.23, J4.23
/OP4: J2.25, J4.25
/SYSCLK: J1.3, J3.3
/U0: J2.27, J4.27
/U1: J2.29, J4.29
/U2: J2.31, J4.31
/U3: J2.33, J4.33
/U4: J2.35, J4.35
/U5: J2.37, J4.37
/U6: J2.6, J4.6
/U7: J2.8, J4.8
/U8: J2.10, J4.10
/U9: J2.12, J4.12
/U10: J2.14, J4.14
/U11: J2.16, J4.16
/U12: J2.18, J4.18
/U13: J2.20, J4.20
/U14: J2.22, J4.22
/U15: J2.24, J4.24
/U16: J2.26, J4.26
/U17: J2.28, J4.28
/U18: J2.30, J4.30
/U19: J2.32, J4.32
/U20: J2.34, J4.34
/U21: J2.36, J4.36
/U22: J2.38, J4.38
/~SYSRST: J1.1, J3.1

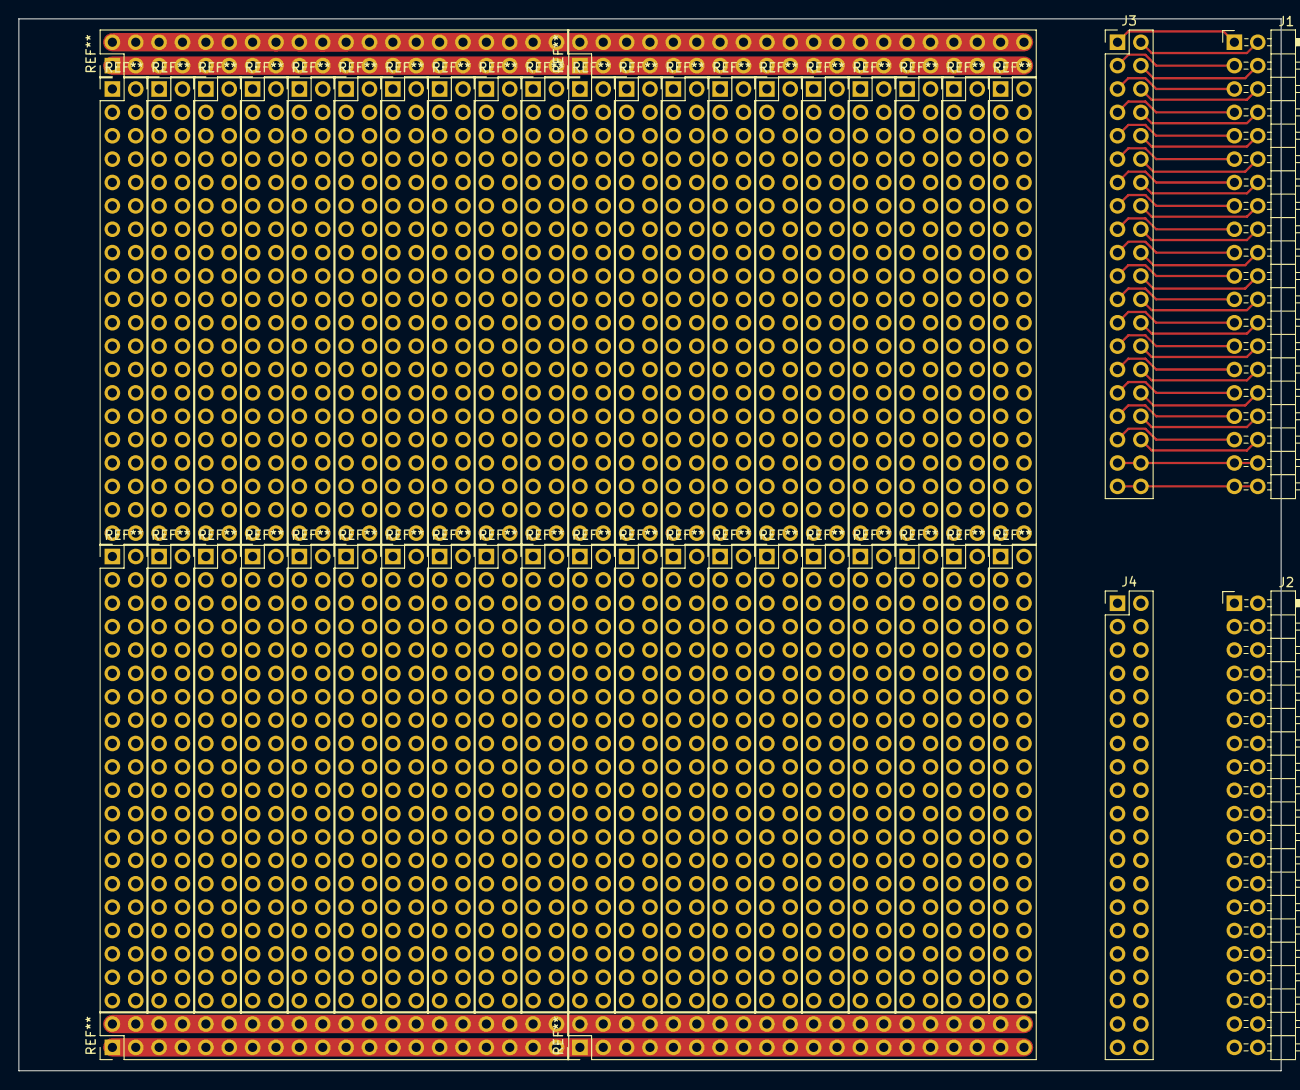
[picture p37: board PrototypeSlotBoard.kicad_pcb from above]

Board: 2 copper layers, 137.2 x 114.3 mm, 4 parts (0 on the bottom side), 74 nets.

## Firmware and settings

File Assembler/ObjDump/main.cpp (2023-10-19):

#include "ObjDump.h"

#include <fstream>
#include <iostream>

int main(int argc, char **argv) {
    std::ifstream inputFile(argv[1], std::ios::in | std::ios::binary);

    if (!inputFile.is_open()) {
        std::cerr << "Missing input file" << std::endl;
        return -1;
    }

    std::cout << "Dummping " << argv[1] << std::endl;
    objdump(inputFile);
    return 0;
}

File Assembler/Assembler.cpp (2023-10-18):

#include <fstream>
#include <map>
#include <iostream>
#include <iomanip>
#include <iterator>
#include <algorithm>

#include "Assembler.h"
#include "Helpers.h"

std::vector<CodeLabel_t> labels;

void outputCompiledCode(std::vector<CompiledLine_t> compiledCode) {
    std::ofstream hexFile("a.hex");
    std::ofstream binFile("a.bin",  std::ios::out | std::ios::binary);
    hexFile << "v2.0 raw" << std::endl;

    std::cout << "Address   Compiled    Raw" << std::endl;
    for (int i = 0; i < compiledCode.size(); i++) {
        std::cout << std::right << std::setw(3) << std::setfill(' ') << std::uppercase << std::hex << compiledCode.at(i).address << ":" << std::setw(6) << " ";

        if (compiledCode.at(i).instruction != DB) {
            std::cout << std::setw(2) << std::setfill('0') << std::uppercase << std::hex << compiledCode.at(i).instruction << " ";
            hexFile << std::setw(2) << std::setfill('0') << std::uppercase << std::hex << compiledCode.at(i).instruction << " ";
            binFile << static_cast<unsigned char>(compiledCode.at(i).instruction & 0xFF);
        }

        if (compiledCode.at(i).rawOperand != "") {
            std::cout << std::setw(2) << std::setfill('0') << std::uppercase << std::hex << compiledCode.at(i).operand << " "  << std::setfill(' ') << std::setw(6) << " ";
            hexFile << std::setw(2) << std::setfill('0') << std::uppercase << std::hex << compiledCode.at(i).operand << std::endl;
            binFile << static_cast<unsigned char>(compiledCode.at(i).operand & 0xFF);

            if (compiledCode.at(i).instruction == DB) {
                std::cout << "   ";
            }
        } else {
            std::cout << std::setfill(' ') << std::setw(9) << " ";
        }

        std::cout << compiledCode.at(i).rawCode << std::endl;
    }
}

std::vector<CompiledLine_t> assemble(std::istream &asmfile) {
    std::string line;
    std::vector<CodeLine_t> rawCode;
    int lineNumber = 1;
    std::vector<CompiledLine_t> compiledLine;
    labels.clear();

    // Read entire file into memory
    while (std::getline(asmfile, line)) {
        if (line != "") {
            rawCode.push_back({lineNumber, reduce(line), {}});
        }

        lineNumber++;
    }

    std::vector<CodeLine_t>::iterator it = rawCode.begin();
    std::string temp;
    int currentAddress = 0;

    // tokenize each line of code.
    while (it != rawCode.end()) {
        std::stringstream ss(it->line);
        while(std::getline(ss, temp, ' ')) {
            if (temp.substr(0, 1) == ";") {
                break;
            }

            if (temp.find(";") == std::string::npos) {
                it->tokens.push_back(temp);
            }
        }

        for (int i = 0; i < it->tokens.size(); i++) {
            // Gather the labels.
            if (it->tokens.at(i).find(":") != std::string::npos) {
                std::string::difference_type n = std::count(it->tokens.at(i).begin(), it->tokens.at(i).end(), ':');
                if (n > 1) {
                    std::cerr << "Error: line " << it->lineNumber << " Syntax error too many ':' in label - " << it->line << std::endl;
                    return {};
                }
                std::string strippedLabel = it->tokens.at(i).substr(0, it->tokens.at(i).find(":"));
                std::vector<CodeLabel_t>::iterator dupeIt = std::find_if(labels.begin(), labels.end(), find_name(strippedLabel));
                if (dupeIt != labels.end()) {
                    std::cerr << "Error: Line " << it->lineNumber << " duplicate label found '" << labels.at(i).name << "' first referenced on line " << dupeIt->lineNumber << std::endl;
                    return {};
                }
                labels.push_back({it->lineNumber, currentAddress, strippedLabel});
            }

            if ((isEqual(it->tokens.at(i), "LDA")) || (isEqual(it->tokens.at(i), "STA")) ||
                (isEqual(it->tokens.at(i), "LDB")) || (isEqual(it->tokens.at(i), "STB")) ||
                (isEqual(it->tokens.at(i), "STB")) || (isEqual(it->tokens.at(i), "ADD")) ||
                (isEqual(it->tokens.at(i), "SUB")) || (isEqual(it->tokens.at(i), "OUT")) ||
                (isEqual(it->tokens.at(i), "JMP")) || (isEqual(it->tokens.at(i), "JPZ")) ||
                (isEqual(it->tokens.at(i), "JPC"))) {

                if (it->tokens.size() < i+2) {
                    std::cerr << "Error: line " << it->lineNumber << " Operand missing - " << it->line << std::endl;
                    return {};
                } else {
                    std::string operand = it->tokens.at(i+1);
                    if (operand.find("[") != std::string::npos) {
                        compiledLine.push_back({currentAddress, getInstructionEnum(it->tokens.at(i), true), operand, 0, it->line, it->lineNumber});
                    } else {
                        int number = parseNumber(operand);
                        if (number == -1) {
                            std::cerr << "Error: line " << it->lineNumber << " Invalid number format - " << it->line << std::endl;
                            return {};
                        } else if (number > 255) {
                            std::cerr << "Error: line " << it->lineNumber << " Number '"<< number << "' exceeds 8 bit max 255 - " << it->line << std::endl;
                            return {};
                        }
                        compiledLine.push_back({currentAddress, getInstructionEnum(it->tokens.at(i), false), operand, parseNumber(operand), it->line, it->lineNumber});
                    }
                    currentAddress += getInstructionSize(getInstructionEnum(it->tokens.at(i), true));
                }
            } else if ((isEqual(it->tokens.at(i), "HLT")) || (isEqual(it->tokens.at(i), "OUTA")) ||
                       (isEqual(it->tokens.at(i), "OUTB")) || (isEqual(it->tokens.at(i), "NOP"))) {

                if (it->tokens.size() > i+1) {
                    std::cerr << "Error: line " << it->lineNumber << " Instruction " << it->tokens.at(i) << " does not support operands - " << it->line << std::endl;
                    return {};
                }
                compiledLine.push_back({currentAddress, getInstructionEnum(it->tokens.at(i), false), "", 0, it->line, it->lineNumber});
                currentAddress += getInstructionSize(getInstructionEnum(it->tokens.at(i), false));
            } else if (isEqual(it->tokens.at(i), "DB")) {
                if (it->tokens.size() < i+2) {
                    std::cerr << "Error: line " << it->lineNumber << " Missing variable initializer - " << it->line << std::endl;
                    return {};
                }

                compiledLine.push_back({currentAddress, DB, it->tokens.at(i+1), std::stoi(it->tokens.at(i+1)), it->line, it->lineNumber});
                currentAddress++;
            }
        }

        ++it;
    }
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

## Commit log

2023-09-28 Adding base logism circuits
2023-09-29 Adding registers and alu to main circuit
2023-10-16 Adding assembler and adding reference to readme
2023-10-17 Updating assembler
2023-10-17 Unit testing assembler
2023-10-18 Updating main.cpp to abort if no file and updating readme for assembler
2023-11-11 Updating instruction deocrder emulator and kicad schematics
    [DoubleRow4SlotBackplane-B_Cu.gbl, DoubleRow4SlotBackplane-B_Mask.gbs, DoubleRow4SlotBackplane-B_Paste.gbp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]
2023-11-14 Adding 6 slot backplane files
    [DoubleRow4SlotBackplane-B_Cu.gbl, DoubleRow4SlotBackplane-B_Mask.gbs, DoubleRow4SlotBackplane-B_Paste.gbp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]
2023-11-14 adding pcb layouts for clock module
    [ClockModule.fzz]
